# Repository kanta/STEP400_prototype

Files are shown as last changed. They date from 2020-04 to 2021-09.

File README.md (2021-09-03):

## STEP400_prototype

This repository has been retained for data storage, but is no longer being updated.

Please visit https://github.com/ponoor/STEP400.

---

STEP400_proto_r4

STEP400 is a 4-axis stepper motor driver designed for art or design projects. STEP400 combines the following elements into one single board:

- [Arduino Zero](https://www.arduino.cc/en/Guide/ArduinoZero)
- Ethernet shield
- Four stepper motor drivers
- Sensor inputs for homing and limiting

The current firmware is focused on working with [Open Sound Control](http://opensoundcontrol.org/) (OSC) via Ethernet, which is a common protocol for creative coding environments, like openFrameworks, Processing, Max, Unity, or Touch Designer.

Stepper driver chips are STMicroelectronics's [powerSTEP01](https://www.st.com/en/motor-drivers/powerstep01.html) which provide most of functionalities as a stepper driver.

## Repository Contents

This repo is temporal place for working. All information will be moved to a new repo when the clean up is done.

### Firmware
[/rev4/STEP400_proto_r4_firmware/STEP400_proto_r4_firmware/](https://github.com/kanta/STEP400_prototype/tree/master/rev4/STEP400_proto_r4_firmware/STEP400_proto_r4_firmware)

Source files for the firmware. Some Visual Studio files are included but you can open .ino file with Arduino IDE.

### Hardware
[/rev4/hardware/](https://github.com/kanta/STEP400_prototype/tree/master/rev4/hardware)

PCB design files for Eagle.

## Firmware dependency
- **[OSC Library](https://github.com/CNMAT/OSC)** from CNMAT
- **[Ponoor PowerSTEP01 Library](https://github.com/ponoor/Ponoor_PowerSTEP01_Library)**
- **[ArduinoJSON Library](https://arduinojson.org/)**
- **[Adafruit SleepyDog Arduino Library](https://github.com/adafruit/Adafruit_SleepyDog)**

## Examples
### Max
https://github.com/kanta/STEP400_prototype/blob/master/rev4/STEP400_proto_r4.maxpat

### openFrameworks
https://github.com/ponoor/step-series-example-openFrameworks

### Unity
https://github.com/ponoor/step-series-example-Unity

### Touch Designer
https://github.com/ponoor/step-series-example-TouchDesigner

## Documentation
Now working on [Wiki](https://github.com/kanta/STEP400_prototype/wiki).

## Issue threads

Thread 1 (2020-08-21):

Wikiの表記統一

kanta, 2020-08-21:
# ページ全体の見出しは#が1個
## 各コマンドのジャンルは#が2個
### コマンド自体は#が3個

コマンドは```これ（`が3個）```を`これ（`が1個）`に変更する

「返答」という文言は、block code から出す

返答の説明部分、メッセージの文字はblock code（`が1個）でくくる

yuskid, 2020-08-21:
正：block code（`が3個）でくくる

yuskid, 2020-08-21:
手順メモ
1. 「##」で検索、「###」に置換
2. 「```」で検索、適切な部分（単語/文節）を「`」に置換
3. 返答、メッセージ部分をチェックし、「```」でくくる
4. 改行チェック、エラーチェック

kanta, 2020-09-23:
初期値のリスト
https://docs.google.com/spreadsheets/d/1EAUpzARE69ip6_LolZAv3crpmXGsESjCOz6EqVY1lUo/edit#gid=0

kanta, 2020-09-23:
旧フォーマット
https://github.com/kanta/STEP400_prototype/wiki/%E8%A8%AD%E5%AE%9A%E3%83%BB%E3%83%A6%E3%83%BC%E3%83%86%E3%82%A3%E3%83%AA%E3%83%86%E3%82%A3_old

新フォーマット
https://github.com/kanta/STEP400_prototype/wiki/%E8%A8%AD%E5%AE%9A%E3%83%BB%E3%83%A6%E3%83%BC%E3%83%86%E3%82%A3%E3%83%AA%E3%83%86%E3%82%A3

kanta, 2020-09-23:
### `/setDestIp`
#### アーギュメント
なし

#### 実行可能タイミング
常時

#### 説明
モータの状態に変化があったときに通知するメッセージや、問い合わせへ返答するメッセージなどの送り先IPアドレス(`destIp`)を指定します。このメッセージを送信したIPアドレスを`destIp`に設定します。

また、`destIp`が設定されるまでは、STEP400からOSCメッセージの送信は行いませんので、一番最初にこのコマンドを送信してください。

#### 返答

```
/destIp (int)destIp[0] (int)destIp[1] (int)destIp[2] (int)destIp[3] (bool)isNewDestIp
```
| アーギュメント | 範囲 | 説明 |
| --- | --- | --- |
| destIp[0-3] | 0-255| destIpの各桁 |
| isNewDestIp | 0-1 | destIpが変更されたかどうかを示します。変更されていると1, すでに同じアドレスが設定されていた場合は0 |

#### 初期値
10.0.0.10

yuskid, 2020-09-23:
・見出し追加（アーギュメント、実行可能タイミング、説明、返答、初期値）
・リスト→表にする（箇条書き部分）

kanta, 2020-09-30:
(bool) enable
1で有効, 0で無効
範囲 0-1

Closed 2020-08-21.

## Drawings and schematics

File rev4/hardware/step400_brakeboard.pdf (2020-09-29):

GND | 10k 10k 10k 10k
Sheet: ABCD | 1 | 2 | 3 | 4 | 5 | 6 | ABCD 1 | 2 | 3 | 4 | 5 | 6

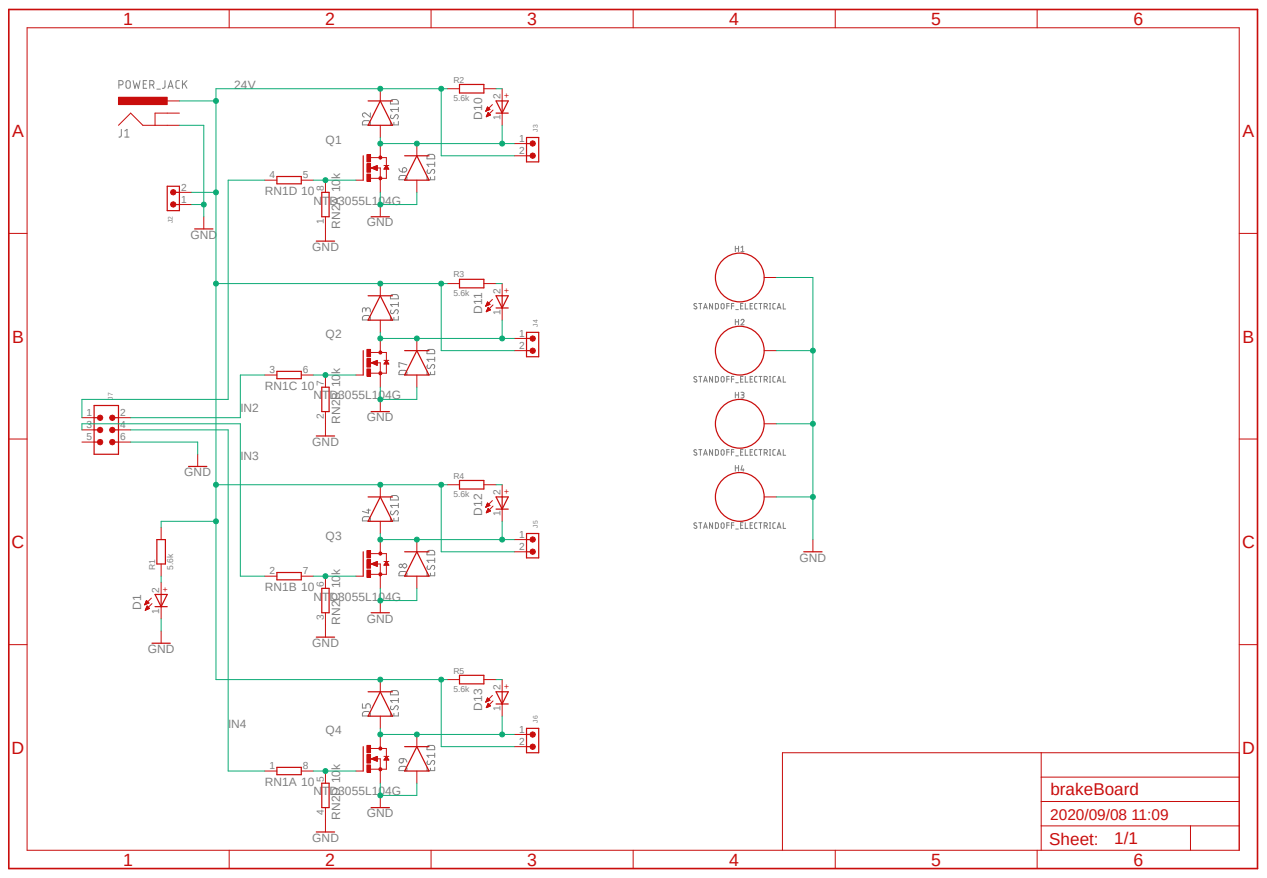
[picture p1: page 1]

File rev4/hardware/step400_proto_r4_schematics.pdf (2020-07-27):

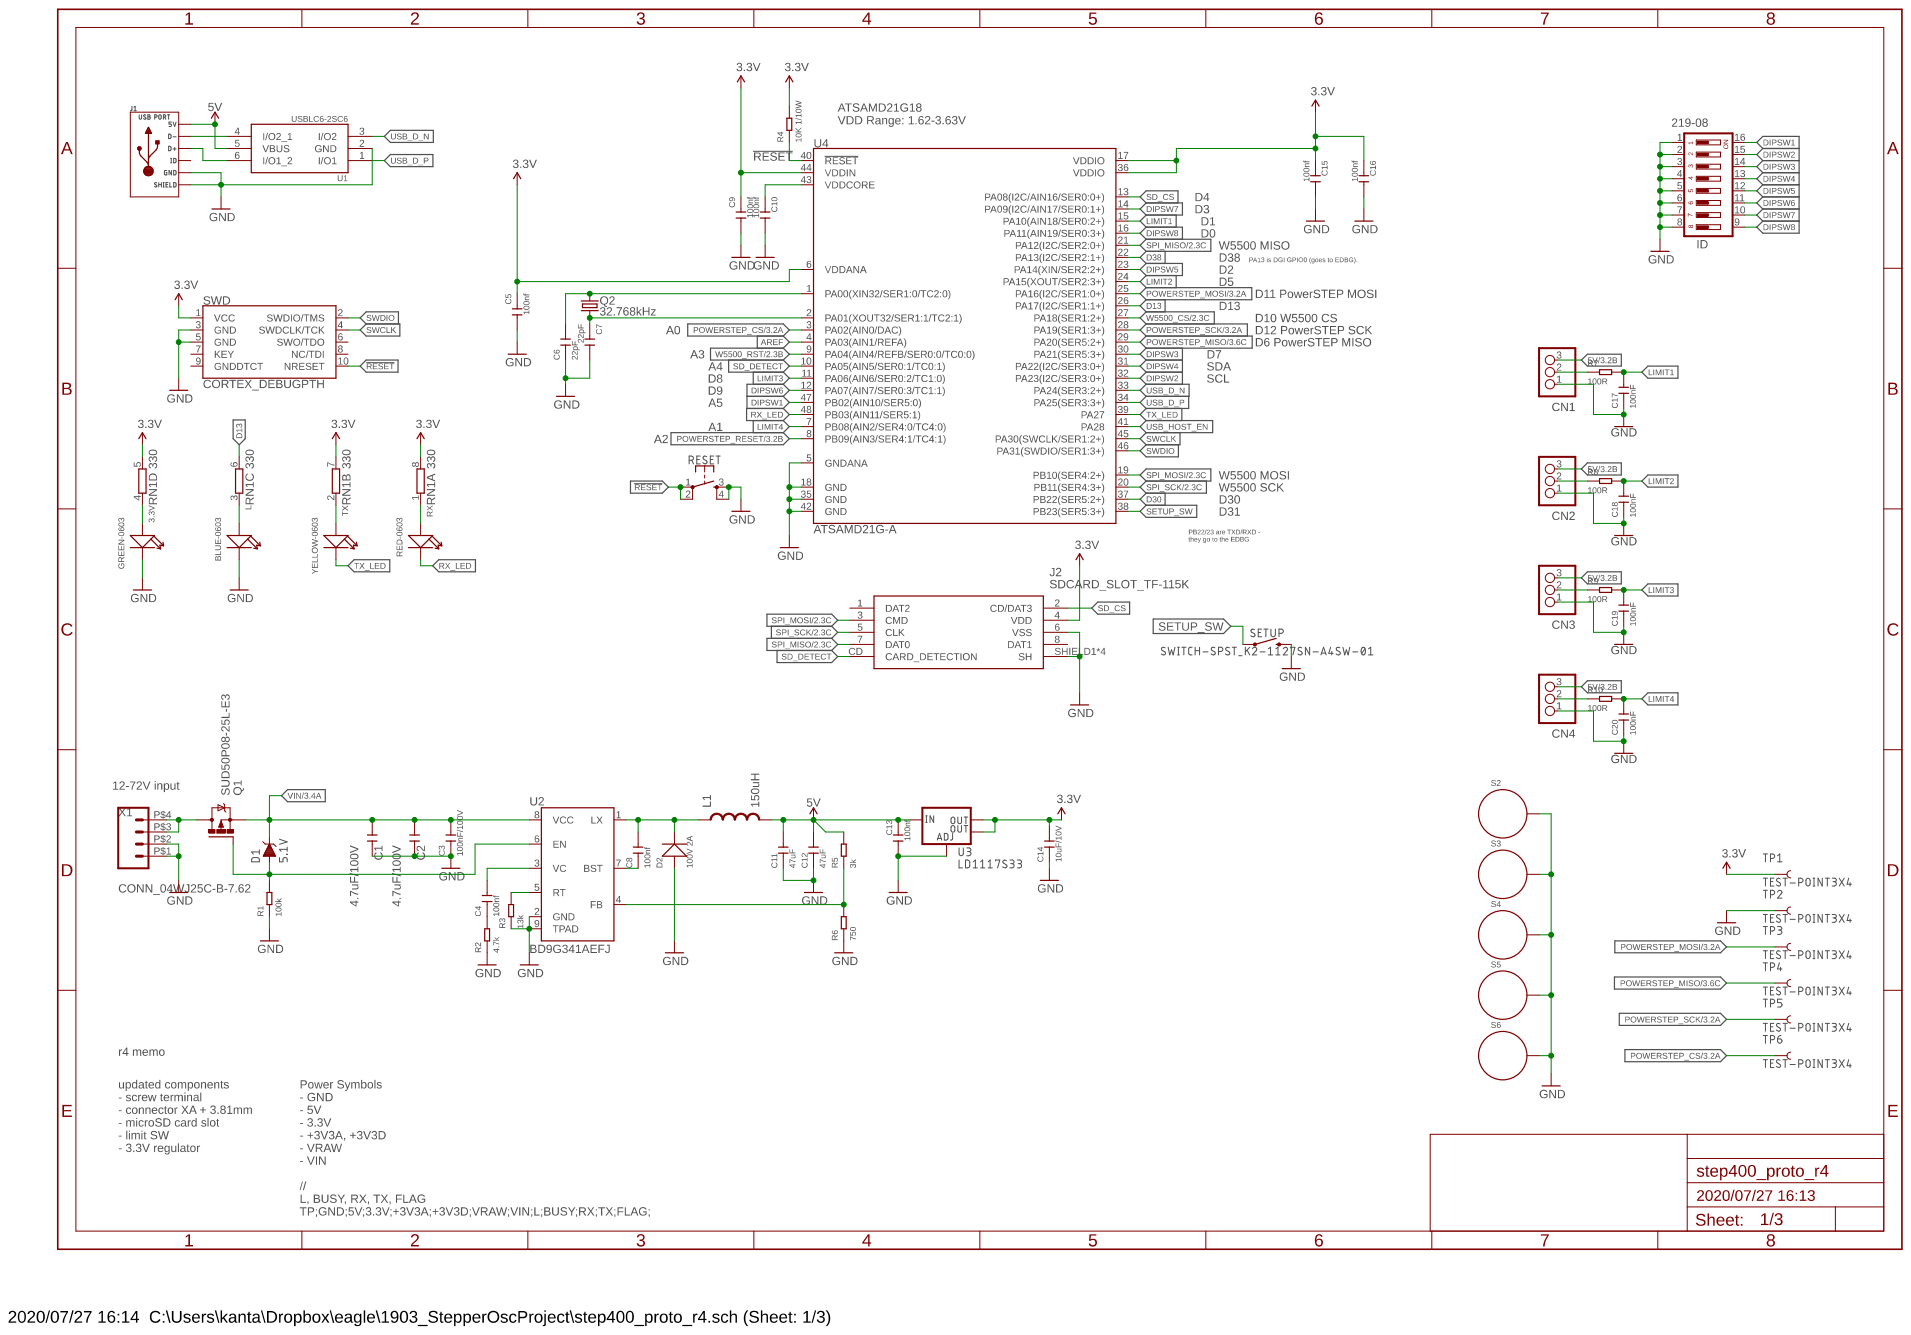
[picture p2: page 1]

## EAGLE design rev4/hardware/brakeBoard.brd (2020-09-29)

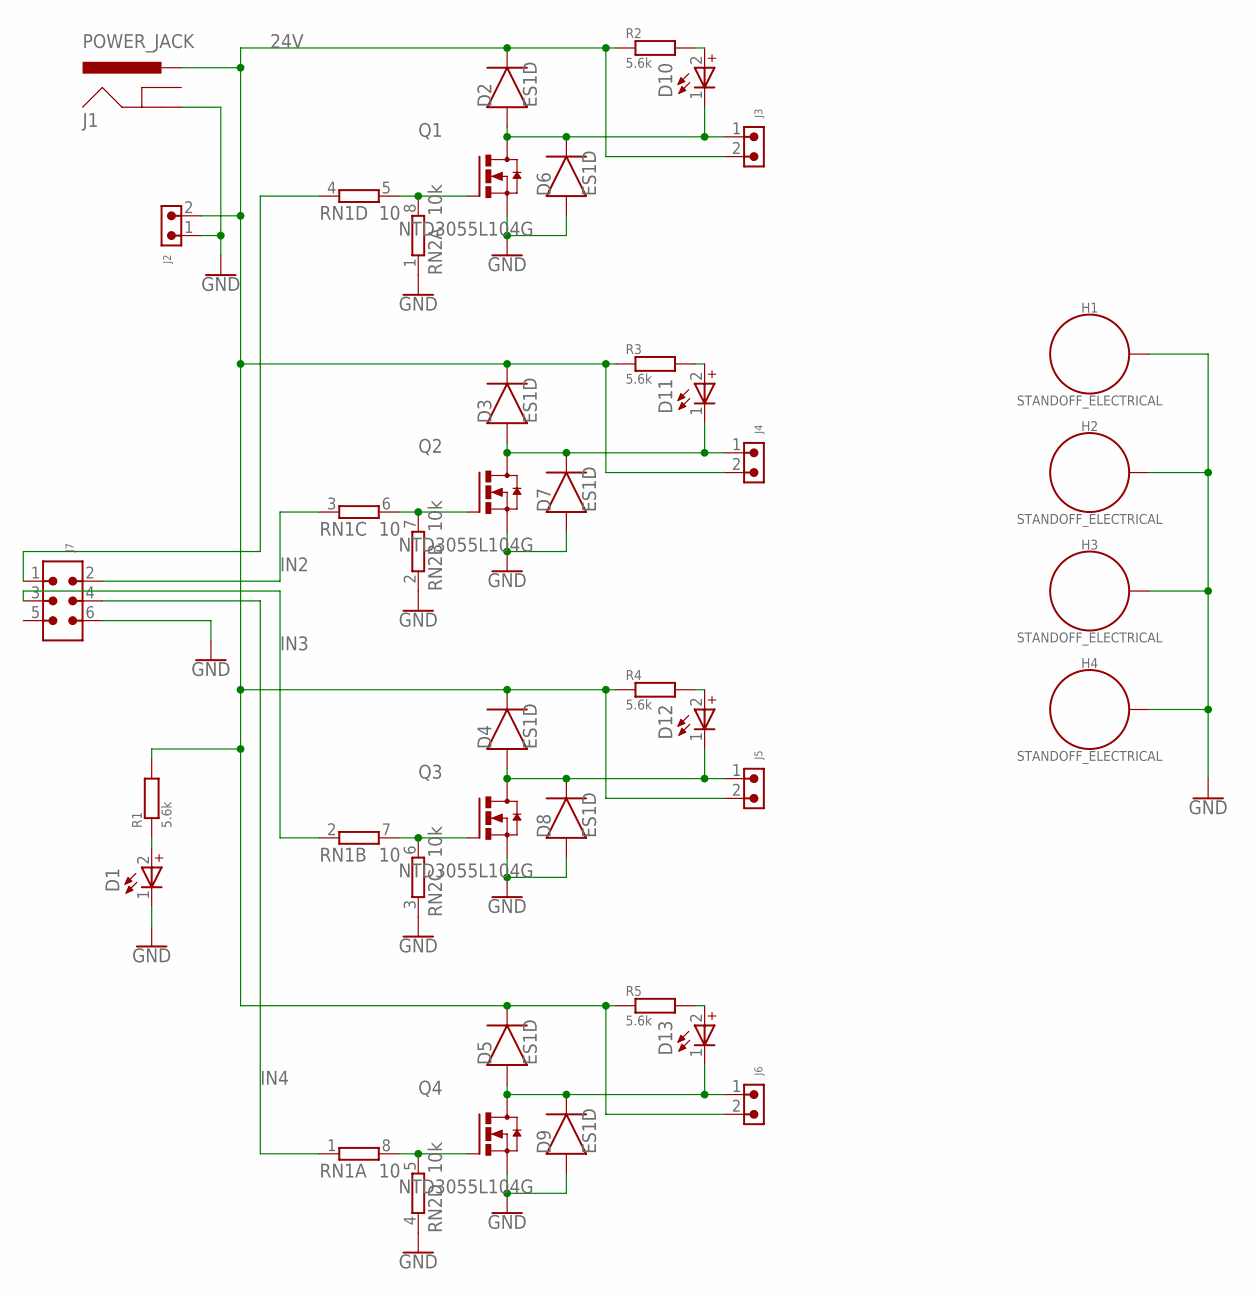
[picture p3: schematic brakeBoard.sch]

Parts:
D1, D10, D11, D12, D13: WL-SMCD_0603_150060GS55040; WL-SMCD_0603
D2, D3, D4, D5, D6, D7, D8, D9: ES1D; DIOM5226X290N
H1, H2, H3, H4: STANDOFF_ELECTRICAL; STANDOFF-ELECTRICAL
J1: POWER_JACK; POWER_JACK_PTH
J2: 691322310002
J3, J4, J5, J6: 691321300002
J7: 6120XX21621_61200621621; 61200621621
Q1, Q2, Q3, Q4: NTD3055L104G; DPAK3
R1, R2, R3, R4, R5: 5.6k; RESC2012X65
RN1: 10; CAY16_LONG_W
RN2: 10k; CAY16_LONG_W

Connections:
24V: D2.1 (C), D3.1 (C), D4.1 (C), D5.1 (C), J1.PWR, J2.2, J3.2, J4.2, J5.2, J6.2, R1.2, R2.1, R3.1, R4.1, R5.1
GND: D1.1 (_), D6.2 (A), D7.2 (A), D8.2 (A), D9.2 (A), H1.P1, H2.P1, H3.P1, H4.P1, J1.GND, J2.1, J7.6, Q1.2 (S), Q2.2 (S), Q3.2 (S), Q4.2 (S), RN2.1, RN2.2 (1), RN2.3 (1), RN2.4 (1)
IN1: J7.1, RN1.4 (1)
IN2: J7.2, RN1.3 (1)
IN3: J7.3, RN1.2 (1)
IN4: J7.4, RN1.1
unnamed: D2.2 (A), D6.1 (C), D10.1 (_), J3.1, Q1.3 (D)
unnamed: D10.2 (+), R2.2
unnamed: Q1.1 (G), RN1.5 (2), RN2.8 (2)
unnamed: D3.2 (A), D7.1 (C), D11.1 (_), J4.1, Q2.3 (D)
unnamed: D11.2 (+), R3.2
unnamed: D4.2 (A), D8.1 (C), D12.1 (_), J5.1, Q3.3 (D)
unnamed: D12.2 (+), R4.2
unnamed: D5.2 (A), D9.1 (C), D13.1 (_), J6.1, Q4.3 (D)
unnamed: D13.2 (+), R5.2
unnamed: Q4.1 (G), RN1.8 (2), RN2.5 (2)
unnamed: Q3.1 (G), RN1.7 (2), RN2.6 (2)
unnamed: Q2.1 (G), RN1.6 (2), RN2.7 (2)
unnamed: D1.2 (+), R1.1

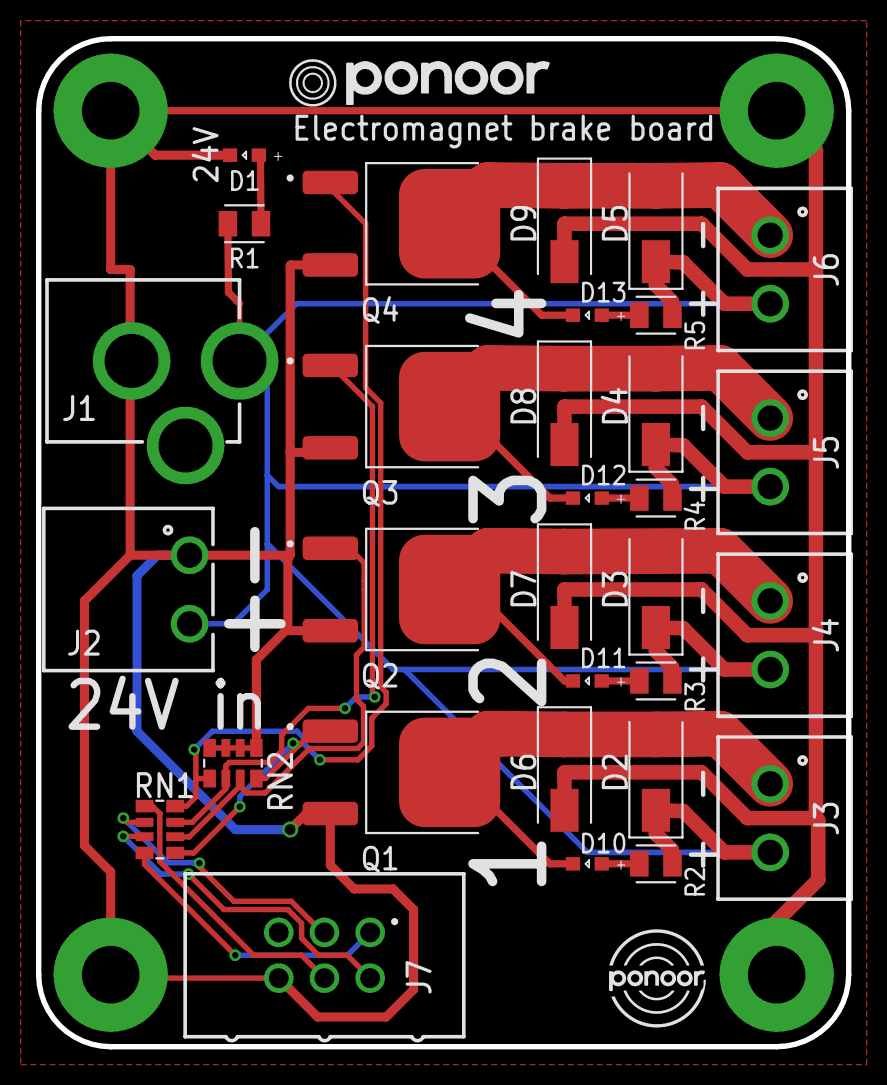
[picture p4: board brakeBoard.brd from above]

Board: 2 copper layers, 45.0 x 56.0 mm, 38 parts (1 on the bottom side), 19 nets.

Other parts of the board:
U$1: PONOOR_LOGO_6MM
U$2, U$3: PONOOR_TEXT_15MM

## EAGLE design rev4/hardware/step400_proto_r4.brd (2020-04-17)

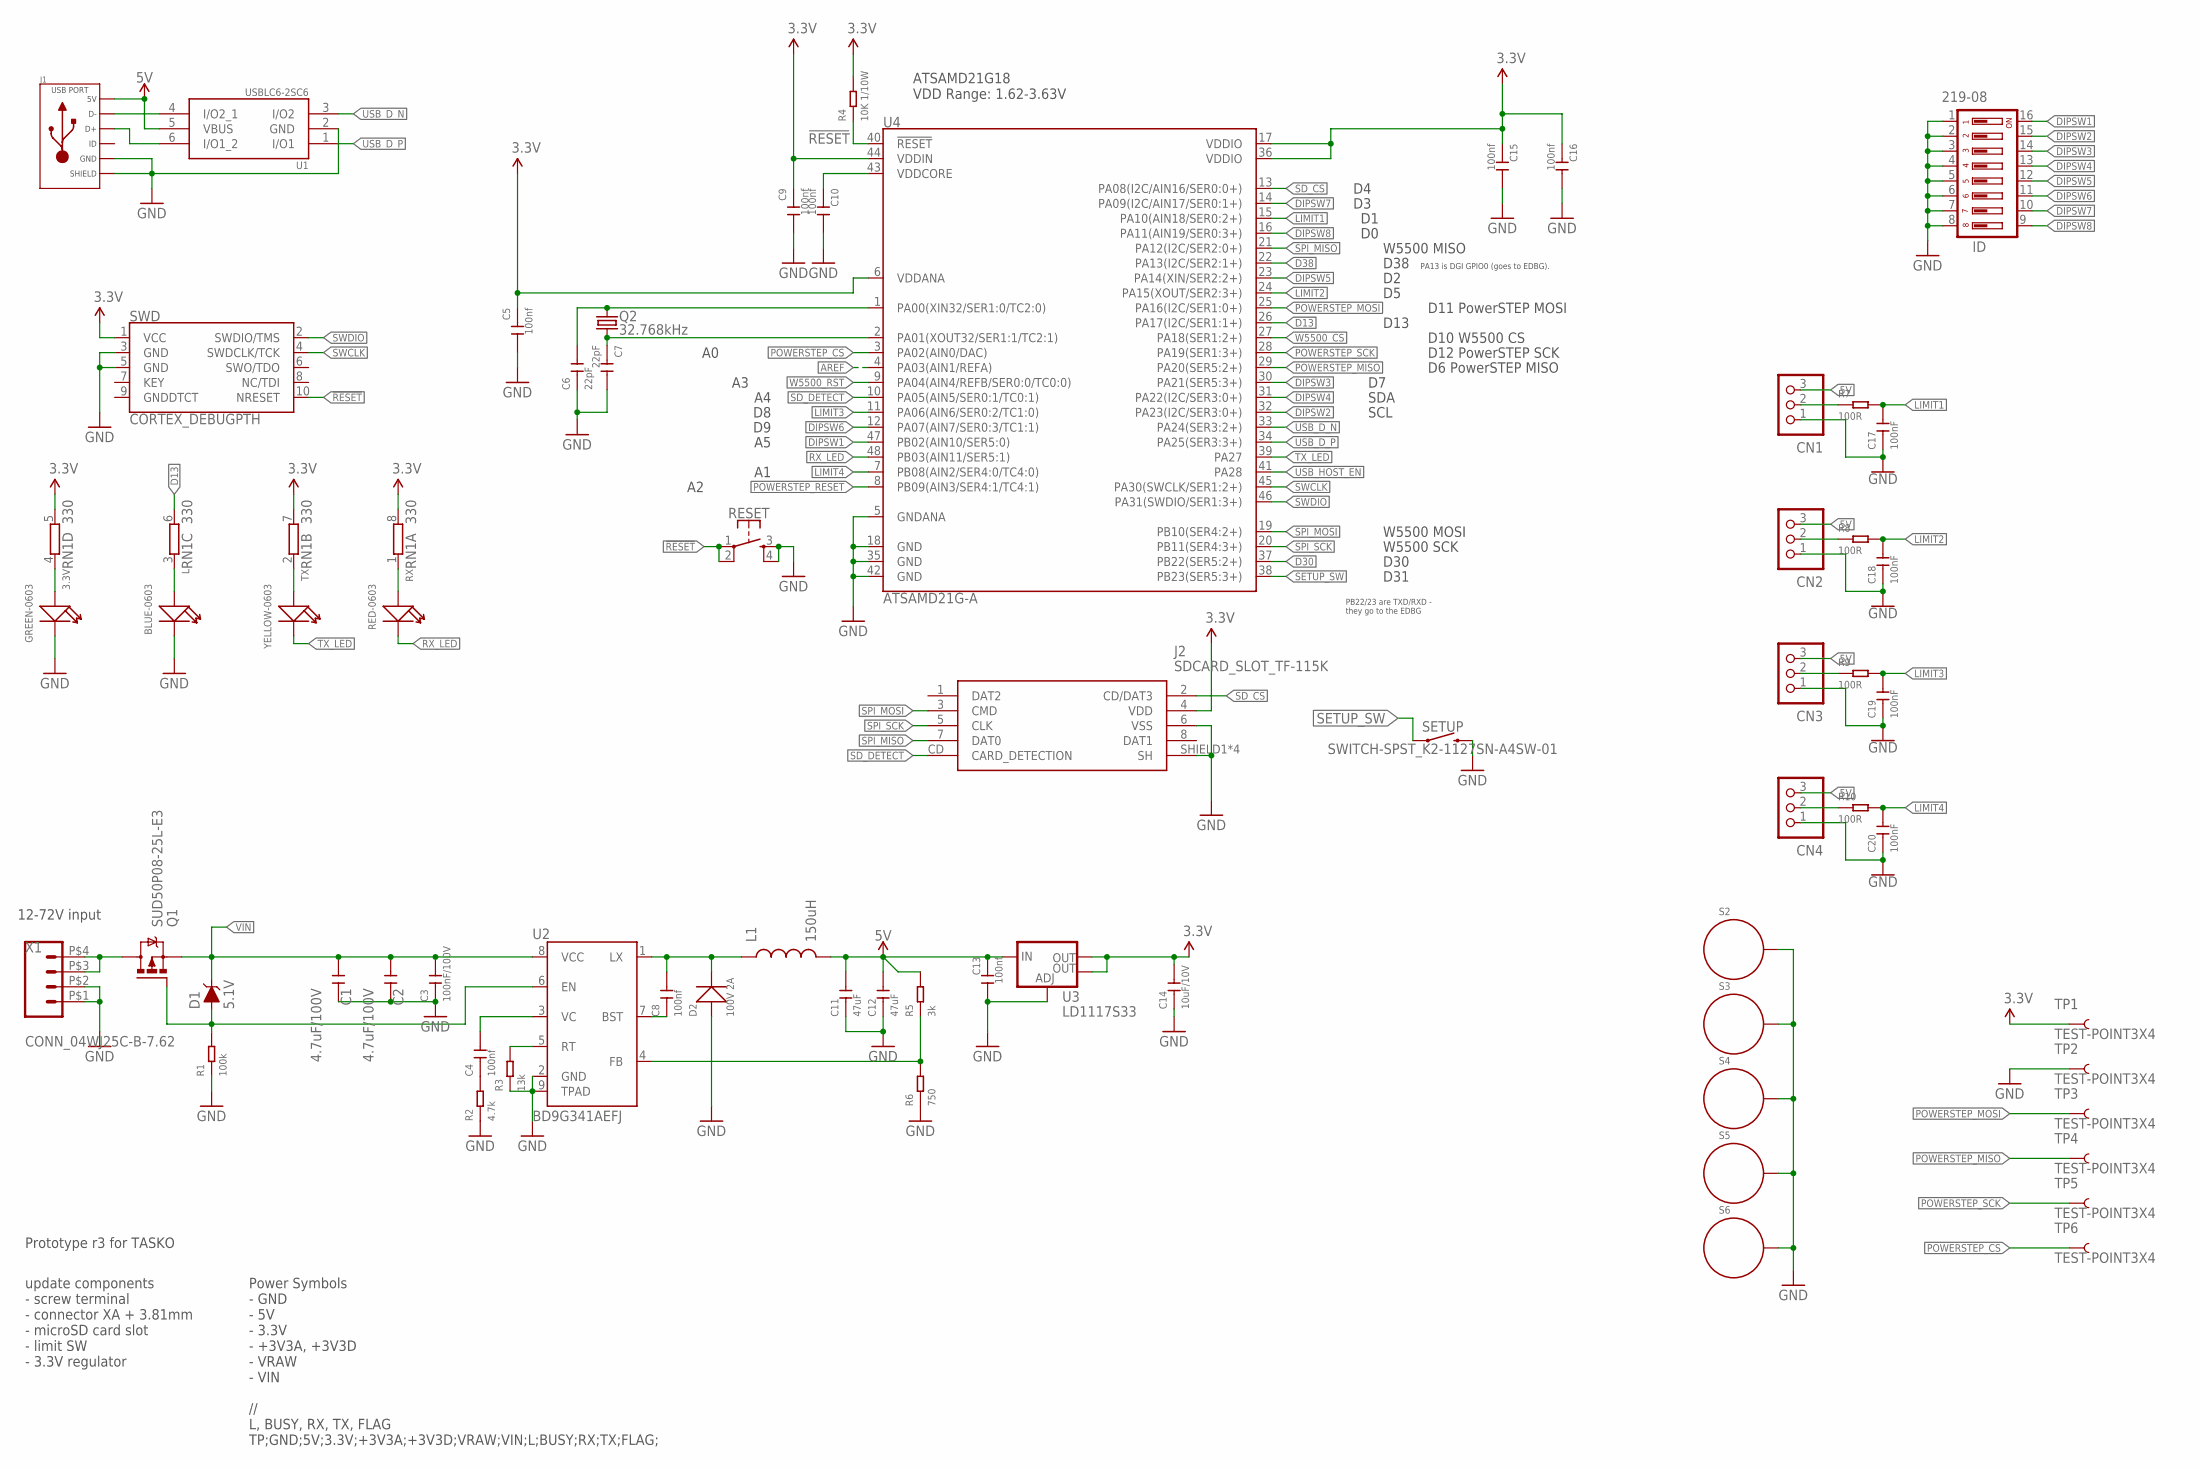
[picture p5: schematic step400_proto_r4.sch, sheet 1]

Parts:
3.3V: GREEN-0603; LED-0603
C1, C2: 4.7uF/100V; C1210
C3: 100nF/100V; C0805
C4, C8: 100nf; C0603
C5, C9, C10, C13, C15, C16: 100nf; C0402
C6, C7: 22pF; C0402
C11, C12: 47uF; C1206
C14: 10uF/10V; C0805
C17, C18, C19, C20: 100nF; C0402
CN1, CN2, CN3, CN4: B3B-XASK-1
D1: 5.1V; SOD-323
D2: 100V 2A; DO-214AC
ID: 219-08; CTS-219-08
J1: USB_MICRO_10118193-0001LF; MICROUSB-FCI-PBAN
J2: SDCARD_SLOT_TF-115K; TF-115K
L: BLUE-0603; LED-0603
L1: 150uH; L5045_L
Q1: SUD50P08-25L-E3; D-PAK_TO252AA
Q2: 32.768kHz; FC-135
R1: 100k; R0603
R2: 4.7k; R0603
R3: 13k; R0603
R4: 10K 1/10W; R0603
R5: 3k; R0603
R6: 750; R0603
R7, R8, R9, R10: 100R; R0603
RESET: MOMENTARY-SWITCH-SPST-2-SMD-5.2MM; TACTILE_SWITCH_SMD_5.2MM
RN1: 330; CAY16_LONG_W
RX: RED-0603; LED-0603
S2, S3, S4, S5, S6: STANDOFF_ELECTRICAL; STANDOFF-ELECTRICAL
SETUP: SWITCH-SPST_K2-1127SN-A4SW-01; K2-1127SN-A4SW-01
SWD: CORTEX_DEBUGPTH; 2X5-PTH-1.27MM
TP1, TP2, TP3, TP4, TP5, TP6: TEST-POINT3X4; PAD.03X.04
TX: YELLOW-0603; LED-0603
U1: USBLC6-2SC6; SOT23-6L
U2: BD9G341AEFJ; SOIC127P600X100-9N
U3: LD1117S33; SOT223
U4: ATSAMD21G-A; TQFP-48
X1: CONN_04WJ25C-B-7.62; WJ25C-B-7.62-4P

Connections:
3.3V: C5.1, C9.1, C14.2, C15.1, C16.1, J2.4 (VDD), R4.2, RN1.5 (2), RN1.7 (2), RN1.8 (2), SWD.1 (VCC), TP1.P$1, U3.2 (OUT), U3.4 (OUT), U4.6 (VDDANA), U4.17 (VDDIO), U4.36 (VDDIO), U4.44 (VDDIN); also elsewhere on the board
5V: C11.2, C12.2, C13.1, CN1.3, CN2.3, CN3.3, CN4.3, J1.1 (5V), L1.P$2 (2), R5.2, U1.5 (VBUS), U3.3 (IN); also elsewhere on the board
!RESET: R4.1, RESET.1, RESET.2, SWD.10 (NRESET), U4.40 (!RESET!)
AREF: U4.4 (PA03(AIN1/REFA))
D13: RN1.6 (2), U4.26 (PA17(I2C/SER1:1+))
D30: U4.37 (PB22(SER5:2+))
D38: U4.22 (PA13(I2C/SER2:1+))
D+: J1.3 (D+), U1.6 (I/O1_2)
DIPSW1: ID.16, U4.47 (PB02(AIN10/SER5:0))
DIPSW2: ID.15, U4.32 (PA23(I2C/SER3:0+))
DIPSW3: ID.14, U4.30 (PA21(SER5:3+))
DIPSW4: ID.13, U4.31 (PA22(I2C/SER3:0+))
DIPSW5: ID.12, U4.23 (PA14(XIN/SER2:2+))
DIPSW6: ID.11, U4.12 (PA07(AIN7/SER0:3/TC1:1))
DIPSW7: ID.10, U4.14 (PA09(I2C/AIN17/SER0:1+))
DIPSW8: ID.9, U4.16 (PA11(AIN19/SER0:3+))
GND: 3.3V.-, C1.2, C2.2, C3.1, C5.2, C6.1, C7.2, C9.2, C10.2, C11.1, C12.1, C13.2, C14.1, C15.2, C16.2, C17.1, C18.1, C19.1, C20.1, CN1.1, CN2.1, CN3.1, CN4.1, D2.1 (+), ID.1, ID.2, ID.3, ID.4, ID.5, ID.6, ID.7, ID.8, J1.5 (GND), J1.S1 (SLD), J1.S2 (SLD), J1.S3 (SLD), J1.S4 (SLD), J1.S5 (SLD), J1.S6 (SLD), J1.S7 (SLD), J1.S8 (SLD), J2.6 (VSS), J2.SHIELD1 (SH), J2.SHIELD2 (SH), J2.SHIELD3 (SH), J2.SHIELD4 (SH), L.-, R1.1, R2.1, R3.1, R6.1, RESET.3, RESET.4, S2.P1, S3.P1, S4.P1, S5.P1, S6.P1, SETUP.P$3 (2), SETUP.P$4 (2), SWD.3 (GND), SWD.5 (GND), TP2.P$1, U1.2 (GND), U2.2 (GND), U2.9 (TPAD), U3.1 (ADJ), U4.5 (GNDANA), U4.18 (GND), U4.35 (GND), U4.42 (GND), X1.P$1 (1), X1.P$2 (2); also elsewhere on the board
LIMIT1: C17.2, R7.2, U4.15 (PA10(AIN18/SER0:2+))
LIMIT2: C18.2, R8.2, U4.24 (PA15(XOUT/SER2:3+))
LIMIT3: C19.2, R9.2, U4.11 (PA06(AIN6/SER0:2/TC1:0))
LIMIT4: C20.2, R10.2, U4.7 (PB08(AIN2/SER4:0/TC4:0))
unnamed: C6.2, Q2.P$2 (2), U4.1 (PA00(XIN32/SER1:0/TC2:0))
unnamed: C4.1, R2.2
unnamed: C7.1, Q2.P$1 (1), U4.2 (PA01(XOUT32/SER1:1/TC2:1))
unnamed: RN1.1, RX.+
unnamed: RN1.2 (1), TX.+
unnamed: R5.1, R6.2, U2.4 (FB)
unnamed: D1.A, Q1.1 (G), R1.2, U2.6 (EN)
unnamed: R3.2, U2.5 (RT)
unnamed: L.+, RN1.3 (1)
unnamed: 3.3V.+, RN1.4 (1)
unnamed: C4.2, U2.3 (VC)
unnamed: CN1.2, R7.1
unnamed: C8.1, U2.7 (BST)
unnamed: CN2.2, R8.1
unnamed: C8.2, D2.2 (-), L1.P$1 (1), U2.1 (LX)
unnamed: CN3.2, R9.1
unnamed: CN4.2, R10.1
unnamed: J1.2 (D-), U1.4 (I/O2_1)
POWERSTEP_CS: TP6.P$1, U4.3 (PA02(AIN0/DAC)); also elsewhere on the board
POWERSTEP_MISO: TP4.P$1, U4.29 (PA20(SER5:2+)); also elsewhere on the board
POWERSTEP_MOSI: TP3.P$1, U4.25 (PA16(I2C/SER1:0+)); also elsewhere on the board
POWERSTEP_RESET: U4.8 (PB09(AIN3/SER4:1/TC4:1)); also elsewhere on the board
POWERSTEP_SCK: TP5.P$1, U4.28 (PA19(SER1:3+)); also elsewhere on the board
RX_LED: RX.-, U4.48 (PB03(AIN11/SER5:1))
SD_CS: J2.2 (CD/DAT3), U4.13 (PA08(I2C/AIN16/SER0:0+))
SD_DETECT: J2.CD (CARD_DETECTION), U4.10 (PA05(AIN5/SER0:1/TC0:1))
SETUP_SW: SETUP.P$1 (1), SETUP.P$2 (1), U4.38 (PB23(SER5:3+))
SPI_MISO: J2.7 (DAT0), U4.21 (PA12(I2C/SER2:0+)); also elsewhere on the board
SPI_MOSI: J2.3 (CMD), U4.19 (PB10(SER4:2+)); also elsewhere on the board
SPI_SCK: J2.5 (CLK), U4.20 (PB11(SER4:3+)); also elsewhere on the board
SWCLK: SWD.4 (SWDCLK/TCK), U4.45 (PA30(SWCLK/SER1:2+))
SWDIO: SWD.2 (SWDIO/TMS), U4.46 (PA31(SWDIO/SER1:3+))
TX_LED: TX.-, U4.39 (PA27)
USB_D_N: U1.3 (I/O2), U4.33 (PA24(SER3:2+))
USB_D_P: U1.1 (I/O1), U4.34 (PA25(SER3:3+))
USB_HOST_EN: U4.41 (PA28)
VDDCORE: C10.1, U4.43 (VDDCORE)
VIN: C1.1, C2.1, C3.2, D1.C, Q1.3 (S), U2.8 (VCC); also elsewhere on the board
VRAW: Q1.4 (D), X1.P$3 (3), X1.P$4 (4)
W5500_CS: U4.27 (PA18(SER1:2+)); also elsewhere on the board
W5500_RST: U4.9 (PA04(AIN4/REFB/SER0:0/TC0:0)); also elsewhere on the board

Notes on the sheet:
PB22/23 are TXD/RXD - they go to the EDBG
PA13 is DGI GPIO0 (goes to EDBG).
ATSAMD21G18 VDD Range: 1.62-3.63V
D30
D12 PowerSTEP SCK
D10 W5500 CS
D11 PowerSTEP MOSI
D13
D6 PowerSTEP MISO
D38
12-72V input
W5500 MISO
W5500 MOSI
W5500 SCK
SDA
SCL
D31
Prototype r3 for TASKO
update components - screw terminal - connector XA + 3.81mm - microSD card slot - limit SW - 3.3V regulator
Power Symbols - GND - 5V - 3.3V - +3V3A, +3V3D - VRAW - VIN // L, BUSY, RX, TX, FLAG TP;GND;5V;3.3V;+3V3A;+3V3D;VRAW;VIN;L;BUSY;RX;TX;FLAG;

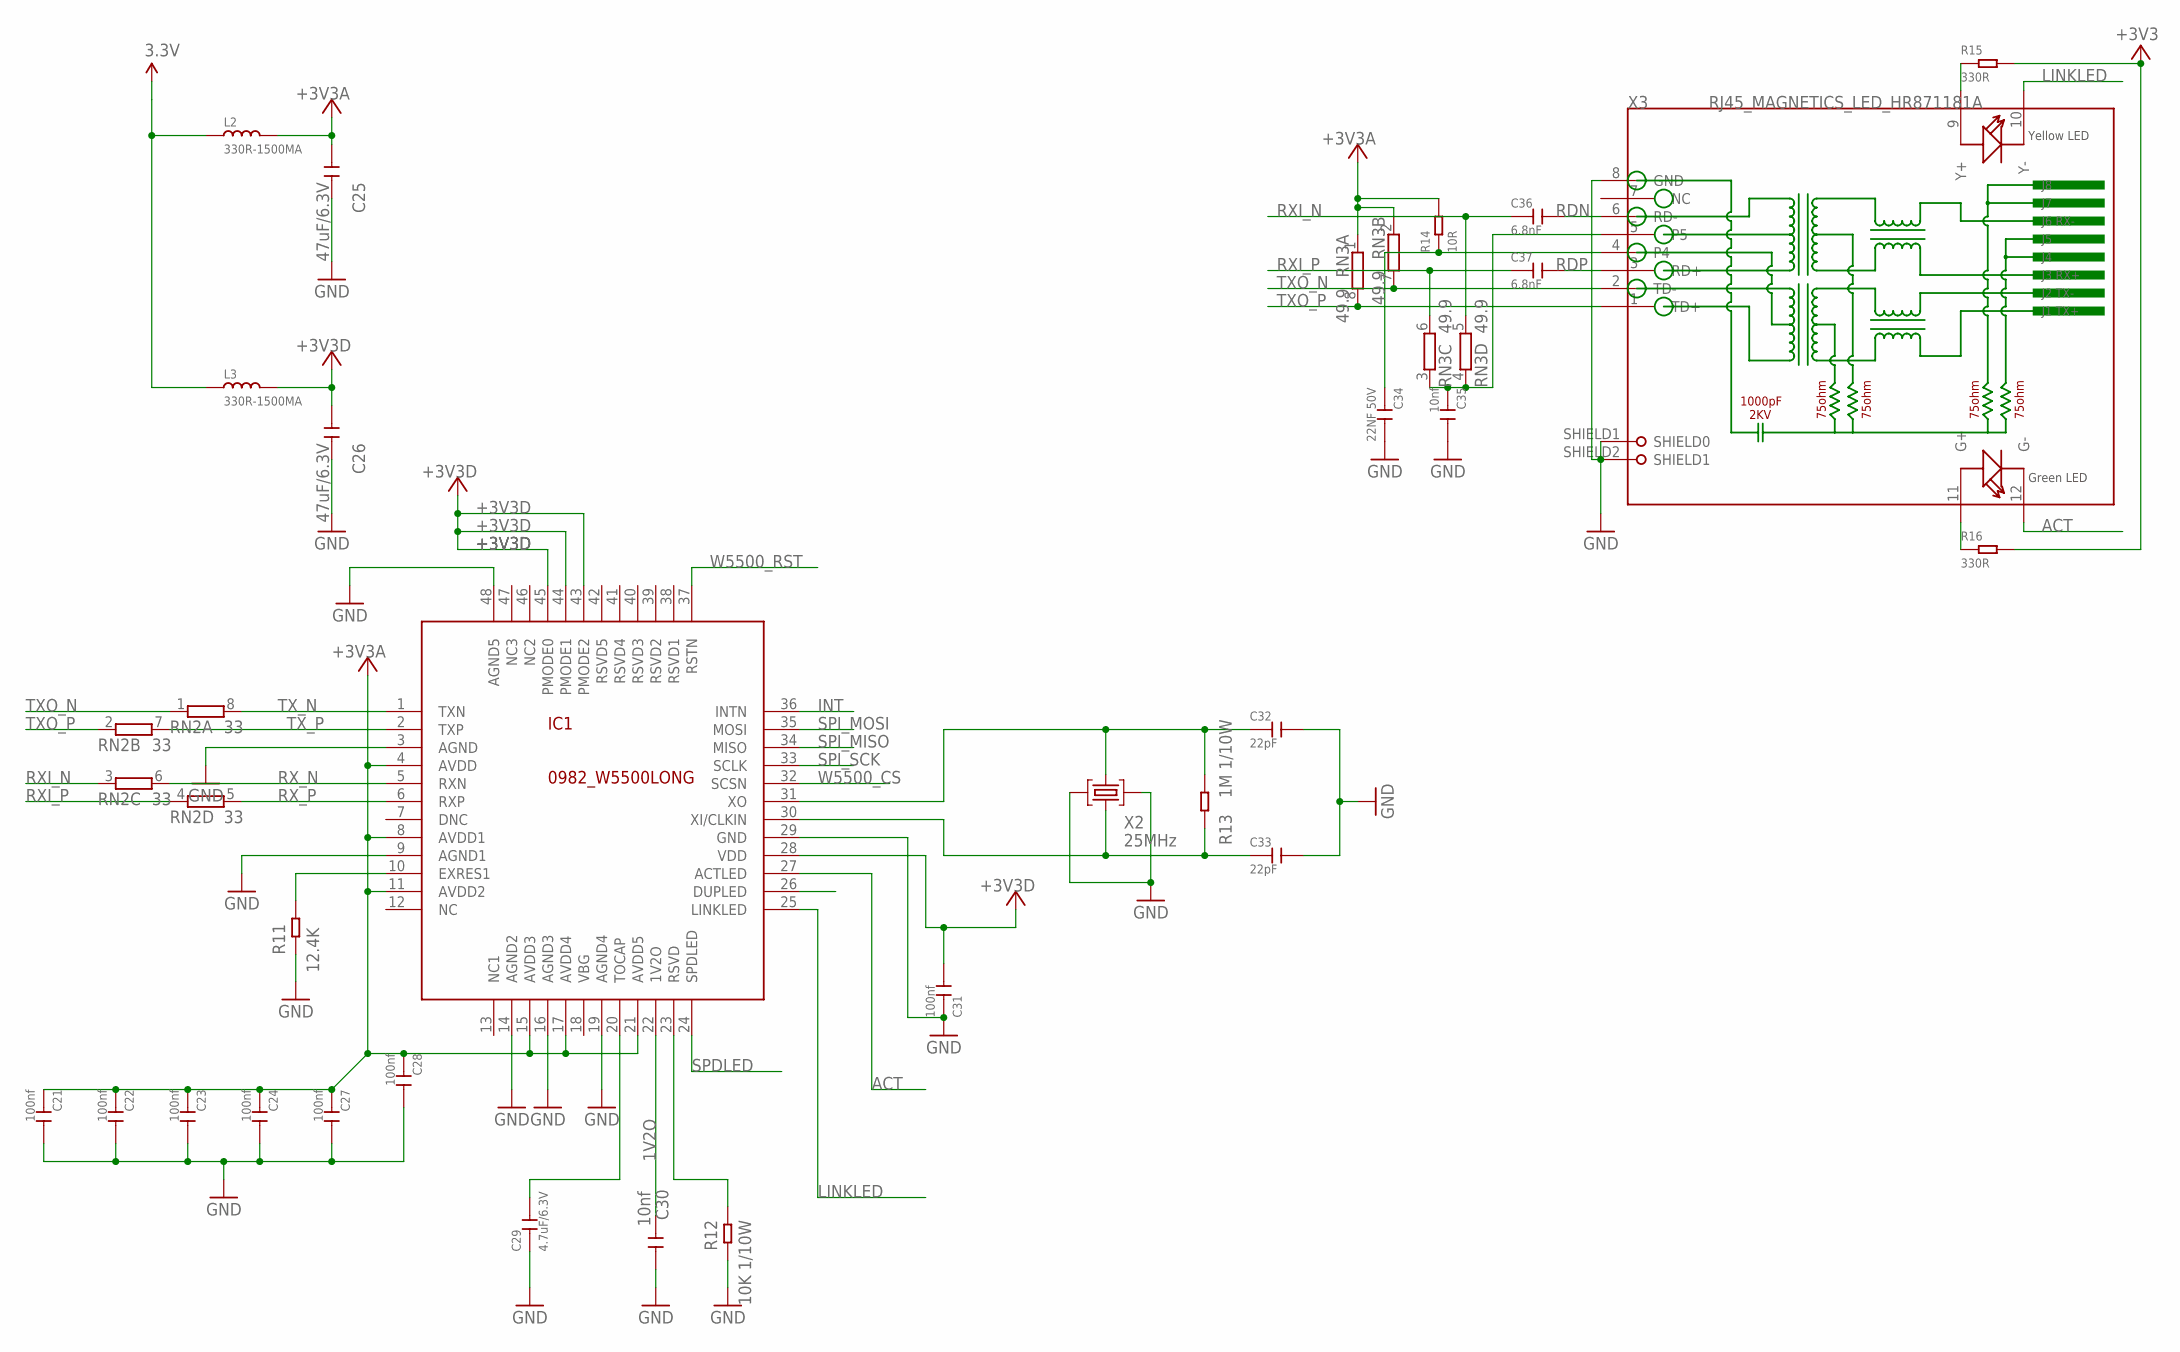
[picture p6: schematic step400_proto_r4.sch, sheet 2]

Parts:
C21, C22, C23, C24, C27, C28, C31: 100nf; C0402
C25, C26: 47uF/6.3V; C1206
C29: 4.7uF/6.3V; C0603
C30, C35: 10nf; C0402
C32, C33: 22pF; C0402
C34: 22NF 50V; C0402
C36, C37: 6.8nF; C0402
IC1: 0982_W5500LONG; TQFP48-LONG
L2, L3: 330R-1500MA; L0805
R11: 12.4K; R0603
R12: 10K 1/10W; R0603
R13: 1M 1/10W; R0603
R14: 10R; R0603
R15, R16: 330R; R0603
RN2: 33; CAY16_LONG_W
RN3: 49.9; CAY16_LONG_W
X2: 25MHz; CRYSTAL-3.2-2.5
X3: RJ45_MAGNETICS_LED_HR871181A; HR871181A

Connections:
1V2O: C30.2, IC1.22 (1V2O)
3.3V: L2.1, L3.1, R15.2, R16.2; also elsewhere on the board
+3V3A: C21.1, C22.1, C23.1, C24.1, C25.1, C27.1, C28.1, IC1.4 (AVDD), IC1.8 (AVDD1), IC1.11 (AVDD2), IC1.15 (AVDD3), IC1.17 (AVDD4), IC1.21 (AVDD5), L2.2, R14.2, RN3.1, RN3.2 (1)
+3V3D: C26.1, C31.2, IC1.28 (VDD), IC1.43 (PMODE2), IC1.44 (PMODE1), IC1.45 (PMODE0), L3.2
ACT: IC1.27 (ACTLED), X3.12 (G-)
FDXLED: IC1.26 (DUPLED)
GND: C21.2, C22.2, C23.2, C24.2, C25.2, C26.2, C27.2, C28.2, C29.1, C30.1, C31.1, C32.2, C33.2, C34.2, C35.2, IC1.3 (AGND), IC1.9 (AGND1), IC1.14 (AGND2), IC1.16 (AGND3), IC1.19 (AGND4), IC1.29 (GND), IC1.48 (AGND5), R11.1, R12.1, X2.2 (GND), X2.4 (GND), X3.8 (GND), X3.SHIELD1 (SHIELD0), X3.SHIELD2 (SHIELD1); also elsewhere on the board
INT: IC1.36 (INTN)
LINKLED: IC1.25 (LINKLED), X3.10 (Y-)
unnamed: C32.1, IC1.31 (XO), R13.1, X2.3 (C2)
unnamed: C34.1, R14.1, X3.4
unnamed: C35.1, RN3.3 (1), RN3.4 (1), X3.5
unnamed: R15.1, X3.9 (Y+)
unnamed: R16.1, X3.11 (G+)
unnamed: IC1.23 (RSVD), R12.2
unnamed: C29.2, IC1.20 (TOCAP)
unnamed: IC1.10 (EXRES1), R11.2
NC: IC1.12 (NC)
OSC2E2: C33.1, IC1.30 (XI/CLKIN), R13.2, X2.1 (C1)
RDN: C36.2, X3.6 (RD-)
RDP: C37.2, X3.3 (RD+)
RSVD1: IC1.38 (RSVD1)
RSVD2: IC1.39 (RSVD2)
RSVD3: IC1.40 (RSVD3)
RXI_N: C36.1, RN2.3 (1), RN3.5 (2)
RXI_P: C37.1, RN2.4 (1), RN3.6 (2)
RX_N: IC1.5 (RXN), RN2.6 (2)
RX_P: IC1.6 (RXP), RN2.5 (2)
SPDLED: IC1.24 (SPDLED)
SPI_MISO: IC1.34 (MISO); also elsewhere on the board
SPI_MOSI: IC1.35 (MOSI); also elsewhere on the board
SPI_SCK: IC1.33 (SCLK); also elsewhere on the board
TXO_N: RN2.1, RN3.7 (2), X3.2 (TD-)
TXO_P: RN2.2 (1), RN3.8 (2), X3.1 (TD+)
TX_N: IC1.1 (TXN), RN2.8 (2)
TX_P: IC1.2 (TXP), RN2.7 (2)
W5500_CS: IC1.32 (SCSN); also elsewhere on the board
W5500_RST: IC1.37 (RSTN); also elsewhere on the board

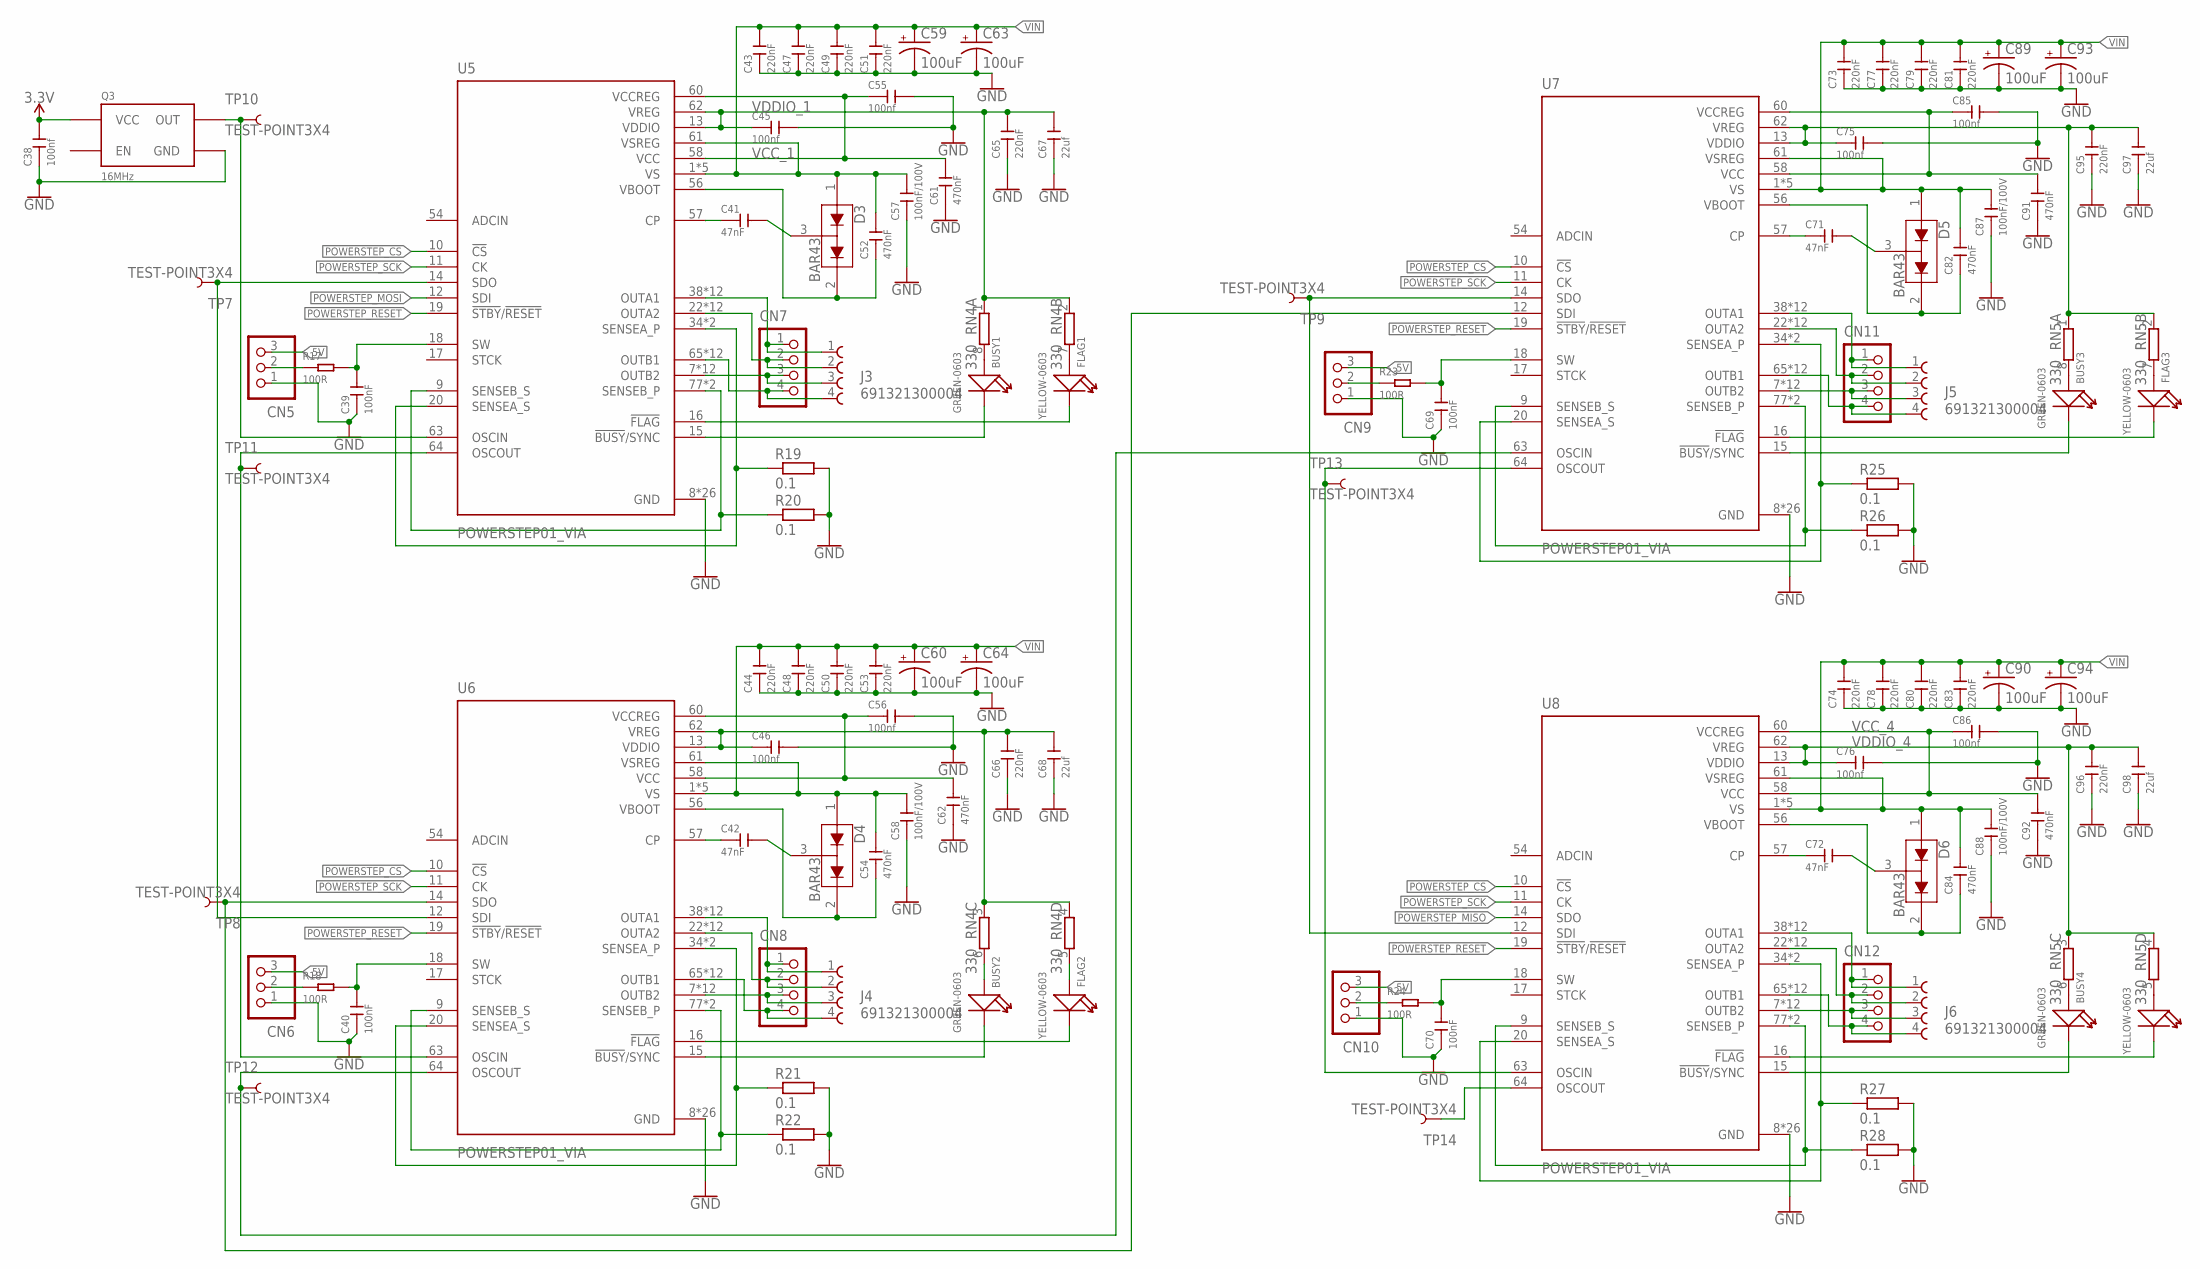
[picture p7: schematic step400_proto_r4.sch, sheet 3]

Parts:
BUSY1, BUSY2, BUSY3, BUSY4: GREEN-0603; LED-0603
C38, C45, C46, C55, C56, C75, C76, C85, C86: 100nf; C0402
C39, C40, C69, C70: 100nF; C0402
C41, C42, C71, C72: 47nF; C0805
C43, C44, C47, C48, C49, C50, C51, C53, C73, C74, C77, C78, C79, C80, C81, C83: 220nF; C0805
C52, C54, C61, C62, C82, C84, C91, C92: 470nF; C0603
C57, C58, C87, C88: 100nF/100V; C0805
C59, C60, C63, C64, C89, C90, C93, C94: 100uF; E5-10,5
C65, C66, C95, C96: 220nF; C0402
C67, C68, C97, C98: 22uf; C0805
CN5, CN6, CN9, CN10: B3B-XASK-1
CN7, CN8, CN11, CN12: B4B-XASK-1
D3, D4, D5, D6: BAR43; SOT23-3
FLAG1, FLAG2, FLAG3, FLAG4: YELLOW-0603; LED-0603
J3, J4, J5, J6: 691321300004
Q3: 16MHz; SG5032
R17, R18, R23, R24: 100R; R0603
R19, R20, R21, R22, R25, R26, R27, R28: 0.1; RESC6332X71N
RN4, RN5: 330; CAY16_LONG_W
TP7, TP8, TP9, TP10, TP11, TP12, TP13, TP14: TEST-POINT3X4; PAD.03X.04
U5, U6, U7, U8: POWERSTEP01_VIA; IC_POWERSTEP01_VIA

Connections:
3.3V: C38.2, Q3.4 (VCC); also elsewhere on the board
5V: CN5.3, CN6.3, CN9.3, CN10.3; also elsewhere on the board
GND: C38.1, C39.1, C40.1, C43.1, C44.1, C45.2, C46.2, C47.1, C48.1, C49.1, C50.1, C51.1, C53.1, C55.2, C56.2, C57.1, C58.1, C59.-, C60.-, C61.1, C62.1, C63.-, C64.-, C65.1, C66.1, C67.1, C68.1, C69.1, C70.1, C73.1, C74.1, C75.2, C76.2, C77.1, C78.1, C79.1, C80.1, C81.1, C83.1, C85.2, C86.2, C87.1, C88.1, C89.-, C90.-, C91.1, C92.1, C93.-, C94.-, C95.1, C96.1, C97.1, C98.1, CN5.1, CN6.1, CN9.1, CN10.1, Q3.2 (GND), R19.2, R20.2, R21.2, R22.2, R25.2, R26.2, R27.2, R28.2, U5.8 (GND), U5.21 (GND), U5.59 (GND), U5.EPAD9 (GND), U5.EPAD9_VIA1 (GND), U5.EPAD9_VIA2 (GND), U5.EPAD9_VIA3 (GND), U5.EPAD9_VIA4 (GND), U5.EPAD9_VIA5 (GND), U5.EPAD9_VIA6 (GND), U5.EPAD9_VIA7 (GND), U5.EPAD9_VIA8 (GND), U5.EPAD9_VIA9 (GND), U5.EPAD9_VIA10 (GND), U5.EPAD9_VIA11 (GND), U5.EPAD9_VIA12 (GND), U5.EPAD9_VIA13 (GND), U5.EPAD9_VIA14 (GND), U5.EPAD9_VIA15 (GND), U5.EPAD9_VIA16 (GND), U5.EPAD9_VIA17 (GND), U5.EPAD9_VIA18 (GND), U5.EPAD9_VIA19 (GND), U5.EPAD9_VIA20 (GND), U5.EPAD9_VIA21 (GND), U5.EPAD9_VIA22 (GND), U6.8 (GND), U6.21 (GND), U6.59 (GND), U6.EPAD9 (GND), U6.EPAD9_VIA1 (GND), U6.EPAD9_VIA2 (GND), U6.EPAD9_VIA3 (GND), U6.EPAD9_VIA4 (GND), U6.EPAD9_VIA5 (GND), U6.EPAD9_VIA6 (GND), U6.EPAD9_VIA7 (GND), U6.EPAD9_VIA8 (GND), U6.EPAD9_VIA9 (GND), U6.EPAD9_VIA10 (GND), U6.EPAD9_VIA11 (GND), U6.EPAD9_VIA12 (GND), U6.EPAD9_VIA13 (GND), U6.EPAD9_VIA14 (GND), U6.EPAD9_VIA15 (GND), U6.EPAD9_VIA16 (GND), U6.EPAD9_VIA17 (GND), U6.EPAD9_VIA18 (GND), U6.EPAD9_VIA19 (GND), U6.EPAD9_VIA20 (GND), U6.EPAD9_VIA21 (GND), U6.EPAD9_VIA22 (GND), U7.8 (GND), U7.21 (GND), U7.59 (GND), U7.EPAD9 (GND), U7.EPAD9_VIA1 (GND), U7.EPAD9_VIA2 (GND), U7.EPAD9_VIA3 (GND), U7.EPAD9_VIA4 (GND), U7.EPAD9_VIA5 (GND), U7.EPAD9_VIA6 (GND), U7.EPAD9_VIA7 (GND), U7.EPAD9_VIA8 (GND), U7.EPAD9_VIA9 (GND), U7.EPAD9_VIA10 (GND), U7.EPAD9_VIA11 (GND), U7.EPAD9_VIA12 (GND), U7.EPAD9_VIA13 (GND), U7.EPAD9_VIA14 (GND), U7.EPAD9_VIA15 (GND), U7.EPAD9_VIA16 (GND), U7.EPAD9_VIA17 (GND), U7.EPAD9_VIA18 (GND), U7.EPAD9_VIA19 (GND)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; also elsewhere on the board
unnamed: TP14.P$1, U8.64 (OSCOUT)
unnamed: BUSY1.+, RN4.8 (2)
unnamed: CN5.2, R17.1
unnamed: C39.2, R17.2, U5.18 (SW)
unnamed: C40.2, R18.2, U6.18 (SW)
unnamed: CN6.2, R18.1
unnamed: C69.2, R23.2, U7.18 (SW)
unnamed: CN9.2, R23.1
unnamed: FLAG1.+, RN4.7 (2)
unnamed: C70.2, R24.2, U8.18 (SW)
unnamed: C41.2, D3.3 (COM)
unnamed: C41.1, U5.57 (CP)
unnamed: CN10.2, R24.1
unnamed: BUSY2.+, RN4.6 (2)
unnamed: FLAG2.+, RN4.5 (2)
unnamed: FLAG1.-, U5.16 (!FLAG)
unnamed: BUSY1.-, U5.15 (!BUSY!/SYNC)
unnamed: R20.1, U5.9 (SENSEB_S), U5.77 (SENSEB_P), U5.82 (SENSEB_P)
unnamed: R19.1, U5.20 (SENSEA_S), U5.34 (SENSEA_P), U5.39 (SENSEA_P)
unnamed: CN7.1, J3.1, U5.38 (OUTA1), U5.42 (OUTA1), U5.53 (OUTA1), U5.EPAD4 (OUTA1), U5.EPAD4_VIA1 (OUTA1), U5.EPAD4_VIA2 (OUTA1), U5.EPAD4_VIA3 (OUTA1), U5.EPAD4_VIA4 (OUTA1), U5.EPAD4_VIA5 (OUTA1), U5.EPAD4_VIA6 (OUTA1), U5.EPAD4_VIA7 (OUTA1), U5.EPAD4_VIA8 (OUTA1)
unnamed: CN7.2, J3.2, U5.22 (OUTA2), U5.33 (OUTA2), U5.37 (OUTA2), U5.EPAD3 (OUTA2), U5.EPAD3_VIA1 (OUTA2), U5.EPAD3_VIA2 (OUTA2), U5.EPAD3_VIA3 (OUTA2), U5.EPAD3_VIA4 (OUTA2), U5.EPAD3_VIA5 (OUTA2), U5.EPAD3_VIA6 (OUTA2), U5.EPAD3_VIA7 (OUTA2), U5.EPAD3_VIA8 (OUTA2)
unnamed: TP7.P$1, U5.14 (SDO), U6.12 (SDI)
unnamed: CN7.3, J3.3, U5.7 (OUTB2), U5.81 (OUTB2), U5.85 (OUTB2), U5.EPAD8 (OUTB2), U5.EPAD8_VIA1 (OUTB2), U5.EPAD8_VIA2 (OUTB2), U5.EPAD8_VIA3 (OUTB2), U5.EPAD8_VIA4 (OUTB2), U5.EPAD8_VIA5 (OUTB2), U5.EPAD8_VIA6 (OUTB2), U5.EPAD8_VIA7 (OUTB2), U5.EPAD8_VIA8 (OUTB2)
unnamed: CN7.4, J3.4, U5.65 (OUTB1), U5.76 (OUTB1), U5.80 (OUTB1), U5.EPAD7 (OUTB1), U5.EPAD7_VIA1 (OUTB1), U5.EPAD7_VIA2 (OUTB1), U5.EPAD7_VIA3 (OUTB1), U5.EPAD7_VIA4 (OUTB1), U5.EPAD7_VIA5 (OUTB1), U5.EPAD7_VIA6 (OUTB1), U5.EPAD7_VIA7 (OUTB1), U5.EPAD7_VIA8 (OUTB1)
unnamed: C42.2, D4.3 (COM)
unnamed: C42.1, U6.57 (CP)
unnamed: BUSY3.+, RN5.8 (2)
unnamed: FLAG3.+, RN5.7 (2)
unnamed: FLAG2.-, U6.16 (!FLAG)
unnamed: BUSY2.-, U6.15 (!BUSY!/SYNC)
unnamed: R22.1, U6.9 (SENSEB_S), U6.77 (SENSEB_P), U6.82 (SENSEB_P)
unnamed: R21.1, U6.20 (SENSEA_S), U6.34 (SENSEA_P), U6.39 (SENSEA_P)
unnamed: TP12.P$1, U6.64 (OSCOUT), U7.63 (OSCIN)
unnamed: CN8.1, J4.1, U6.38 (OUTA1), U6.42 (OUTA1), U6.53 (OUTA1), U6.EPAD4 (OUTA1), U6.EPAD4_VIA1 (OUTA1), U6.EPAD4_VIA2 (OUTA1), U6.EPAD4_VIA3 (OUTA1), U6.EPAD4_VIA4 (OUTA1), U6.EPAD4_VIA5 (OUTA1), U6.EPAD4_VIA6 (OUTA1), U6.EPAD4_VIA7 (OUTA1), U6.EPAD4_VIA8 (OUTA1)
unnamed: CN8.2, J4.2, U6.22 (OUTA2), U6.33 (OUTA2), U6.37 (OUTA2), U6.EPAD3 (OUTA2), U6.EPAD3_VIA1 (OUTA2), U6.EPAD3_VIA2 (OUTA2), U6.EPAD3_VIA3 (OUTA2), U6.EPAD3_VIA4 (OUTA2), U6.EPAD3_VIA5 (OUTA2), U6.EPAD3_VIA6 (OUTA2), U6.EPAD3_VIA7 (OUTA2), U6.EPAD3_VIA8 (OUTA2)
unnamed: CN8.3, J4.3, U6.7 (OUTB2), U6.81 (OUTB2), U6.85 (OUTB2), U6.EPAD8 (OUTB2), U6.EPAD8_VIA1 (OUTB2), U6.EPAD8_VIA2 (OUTB2), U6.EPAD8_VIA3 (OUTB2), U6.EPAD8_VIA4 (OUTB2), U6.EPAD8_VIA5 (OUTB2), U6.EPAD8_VIA6 (OUTB2), U6.EPAD8_VIA7 (OUTB2), U6.EPAD8_VIA8 (OUTB2)
unnamed: CN8.4, J4.4, U6.65 (OUTB1), U6.76 (OUTB1), U6.80 (OUTB1), U6.EPAD7 (OUTB1), U6.EPAD7_VIA1 (OUTB1), U6.EPAD7_VIA2 (OUTB1), U6.EPAD7_VIA3 (OUTB1), U6.EPAD7_VIA4 (OUTB1), U6.EPAD7_VIA5 (OUTB1), U6.EPAD7_VIA6 (OUTB1), U6.EPAD7_VIA7 (OUTB1), U6.EPAD7_VIA8 (OUTB1)
unnamed: BUSY4.+, RN5.6 (2)
unnamed: C82.1, D5.2 (C2), U7.56 (VBOOT)
unnamed: C71.2, D5.3 (COM)
unnamed: C71.1, U7.57 (CP)
unnamed: FLAG4.+, RN5.5 (2)
unnamed: CN11.4, J5.4, U7.65 (OUTB1), U7.76 (OUTB1), U7.80 (OUTB1), U7.EPAD7 (OUTB1), U7.EPAD7_VIA1 (OUTB1), U7.EPAD7_VIA2 (OUTB1), U7.EPAD7_VIA3 (OUTB1), U7.EPAD7_VIA4 (OUTB1), U7.EPAD7_VIA5 (OUTB1), U7.EPAD7_VIA6 (OUTB1), U7.EPAD7_VIA7 (OUTB1), U7.EPAD7_VIA8 (OUTB1)
unnamed: FLAG3.-, U7.16 (!FLAG)
unnamed: BUSY3.-, U7.15 (!BUSY!/SYNC)
unnamed: R26.1, U7.9 (SENSEB_S), U7.77 (SENSEB_P), U7.82 (SENSEB_P)
unnamed: R25.1, U7.20 (SENSEA_S), U7.34 (SENSEA_P), U7.39 (SENSEA_P)
unnamed: TP8.P$1, U6.14 (SDO), U7.12 (SDI)
unnamed: CN11.1, J5.1, U7.38 (OUTA1), U7.42 (OUTA1), U7.53 (OUTA1), U7.EPAD4 (OUTA1), U7.EPAD4_VIA1 (OUTA1), U7.EPAD4_VIA2 (OUTA1), U7.EPAD4_VIA3 (OUTA1), U7.EPAD4_VIA4 (OUTA1), U7.EPAD4_VIA5 (OUTA1), U7.EPAD4_VIA6 (OUTA1), U7.EPAD4_VIA7 (OUTA1), U7.EPAD4_VIA8 (OUTA1)
unnamed: CN11.2, J5.2, U7.22 (OUTA2), U7.33 (OUTA2), U7.37 (OUTA2), U7.EPAD3 (OUTA2), U7.EPAD3_VIA1 (OUTA2), U7.EPAD3_VIA2 (OUTA2), U7.EPAD3_VIA3 (OUTA2), U7.EPAD3_VIA4 (OUTA2), U7.EPAD3_VIA5 (OUTA2), U7.EPAD3_VIA6 (OUTA2), U7.EPAD3_VIA7 (OUTA2), U7.EPAD3_VIA8 (OUTA2)
unnamed: CN11.3, J5.3, U7.7 (OUTB2), U7.81 (OUTB2), U7.85 (OUTB2), U7.EPAD8 (OUTB2), U7.EPAD8_VIA1 (OUTB2), U7.EPAD8_VIA2 (OUTB2), U7.EPAD8_VIA3 (OUTB2), U7.EPAD8_VIA4 (OUTB2), U7.EPAD8_VIA5 (OUTB2), U7.EPAD8_VIA6 (OUTB2), U7.EPAD8_VIA7 (OUTB2), U7.EPAD8_VIA8 (OUTB2)
unnamed: CN12.4, J6.4, U8.65 (OUTB1), U8.76 (OUTB1), U8.80 (OUTB1), U8.EPAD7 (OUTB1), U8.EPAD7_VIA1 (OUTB1), U8.EPAD7_VIA2 (OUTB1), U8.EPAD7_VIA3 (OUTB1), U8.EPAD7_VIA4 (OUTB1), U8.EPAD7_VIA5 (OUTB1), U8.EPAD7_VIA6 (OUTB1), U8.EPAD7_VIA7 (OUTB1), U8.EPAD7_VIA8 (OUTB1)
unnamed: CN12.3, J6.3, U8.7 (OUTB2), U8.81 (OUTB2), U8.85 (OUTB2), U8.EPAD8 (OUTB2), U8.EPAD8_VIA1 (OUTB2), U8.EPAD8_VIA2 (OUTB2), U8.EPAD8_VIA3 (OUTB2), U8.EPAD8_VIA4 (OUTB2), U8.EPAD8_VIA5 (OUTB2), U8.EPAD8_VIA6 (OUTB2), U8.EPAD8_VIA7 (OUTB2), U8.EPAD8_VIA8 (OUTB2)
unnamed: C84.1, D6.2 (C2), U8.56 (VBOOT)
unnamed: C72.2, D6.3 (COM)
unnamed: C72.1, U8.57 (CP)
unnamed: FLAG4.-, U8.16 (!FLAG)
unnamed: BUSY4.-, U8.15 (!BUSY!/SYNC)
unnamed: R28.1, U8.9 (SENSEB_S), U8.77 (SENSEB_P), U8.82 (SENSEB_P)
unnamed: R27.1, U8.20 (SENSEA_S), U8.34 (SENSEA_P), U8.39 (SENSEA_P)
unnamed: CN12.1, J6.1, U8.38 (OUTA1), U8.42 (OUTA1), U8.53 (OUTA1), U8.EPAD4 (OUTA1), U8.EPAD4_VIA1 (OUTA1), U8.EPAD4_VIA2 (OUTA1), U8.EPAD4_VIA3 (OUTA1), U8.EPAD4_VIA4 (OUTA1), U8.EPAD4_VIA5 (OUTA1), U8.EPAD4_VIA6 (OUTA1), U8.EPAD4_VIA7 (OUTA1), U8.EPAD4_VIA8 (OUTA1)
unnamed: CN12.2, J6.2, U8.22 (OUTA2), U8.33 (OUTA2), U8.37 (OUTA2), U8.EPAD3 (OUTA2), U8.EPAD3_VIA1 (OUTA2), U8.EPAD3_VIA2 (OUTA2), U8.EPAD3_VIA3 (OUTA2), U8.EPAD3_VIA4 (OUTA2), U8.EPAD3_VIA5 (OUTA2), U8.EPAD3_VIA6 (OUTA2), U8.EPAD3_VIA7 (OUTA2), U8.EPAD3_VIA8 (OUTA2)
unnamed: Q3.3 (OUT), TP10.P$1, U5.63 (OSCIN)
unnamed: TP11.P$1, U5.64 (OSCOUT), U6.63 (OSCIN)
unnamed: TP13.P$1, U7.64 (OSCOUT), U8.63 (OSCIN)
unnamed: TP9.P$1, U7.14 (SDO), U8.12 (SDI)
POWERSTEP_CS: U5.10 (!CS), U6.10 (!CS), U7.10 (!CS), U8.10 (!CS); also elsewhere on the board
POWERSTEP_MISO: U8.14 (SDO); also elsewhere on the board
POWERSTEP_MOSI: U5.12 (SDI); also elsewhere on the board
POWERSTEP_RESET: U5.19 (!STBY!/!RESET), U6.19 (!STBY!/!RESET), U7.19 (!STBY!/!RESET), U8.19 (!STBY!/!RESET); also elsewhere on the board
POWERSTEP_SCK: U5.11 (CK), U6.11 (CK), U7.11 (CK), U8.11 (CK); also elsewhere on the board
VBOOT_1: C52.1, D3.2 (C2), U5.56 (VBOOT)
VBOOT_2: C54.1, D4.2 (C2), U6.56 (VBOOT)
VCC_1: C55.1, C61.2, U5.58 (VCC), U5.60 (VCCREG)
VCC_2: C56.1, C62.2, U6.58 (VCC), U6.60 (VCCREG)
VCC_3: C85.1, C91.2, U7.58 (VCC), U7.60 (VCCREG)
VCC_4: C86.1, C92.2, U8.58 (VCC), U8.60 (VCCREG)
VDDIO_1: C45.1, C65.2, C67.2, RN4.1, RN4.2 (1), U5.13 (VDDIO), U5.62 (VREG)
VDDIO_2: C46.1, C66.2, C68.2, RN4.3 (1), RN4.4 (1), U6.13 (VDDIO), U6.62 (VREG)
VDDIO_3: C75.1, C95.2, C97.2, RN5.1, RN5.2 (1), U7.13 (VDDIO), U7.62 (VREG)
VDDIO_4: C76.1, C96.2, C98.2, RN5.3 (1), RN5.4 (1), U8.13 (VDDIO), U8.62 (VREG)
VIN: C43.2, C44.2, C47.2, C48.2, C49.2, C50.2, C51.2, C52.2, C53.2, C54.2, C57.2, C58.2, C59.+, C60.+, C63.+, C64.+, C73.2, C74.2, C77.2, C78.2, C79.2, C80.2, C81.2, C82.2, C83.2, C84.2, C87.2, C88.2, C89.+, C90.+, C93.+, C94.+, D3.1 (A1), D4.1 (A1), D5.1 (A1), D6.1 (A1), U5.1 (VS), U5.23 (VS), U5.43 (VS), U5.55 (VS), U5.61 (VSREG), U5.66 (VS), U6.1 (VS), U6.23 (VS), U6.43 (VS), U6.55 (VS), U6.61 (VSREG), U6.66 (VS), U7.1 (VS), U7.23 (VS), U7.43 (VS), U7.55 (VS), U7.61 (VSREG), U7.66 (VS), U8.1 (VS), U8.23 (VS), U8.43 (VS), U8.55 (VS), U8.61 (VSREG), U8.66 (VS); also elsewhere on the board

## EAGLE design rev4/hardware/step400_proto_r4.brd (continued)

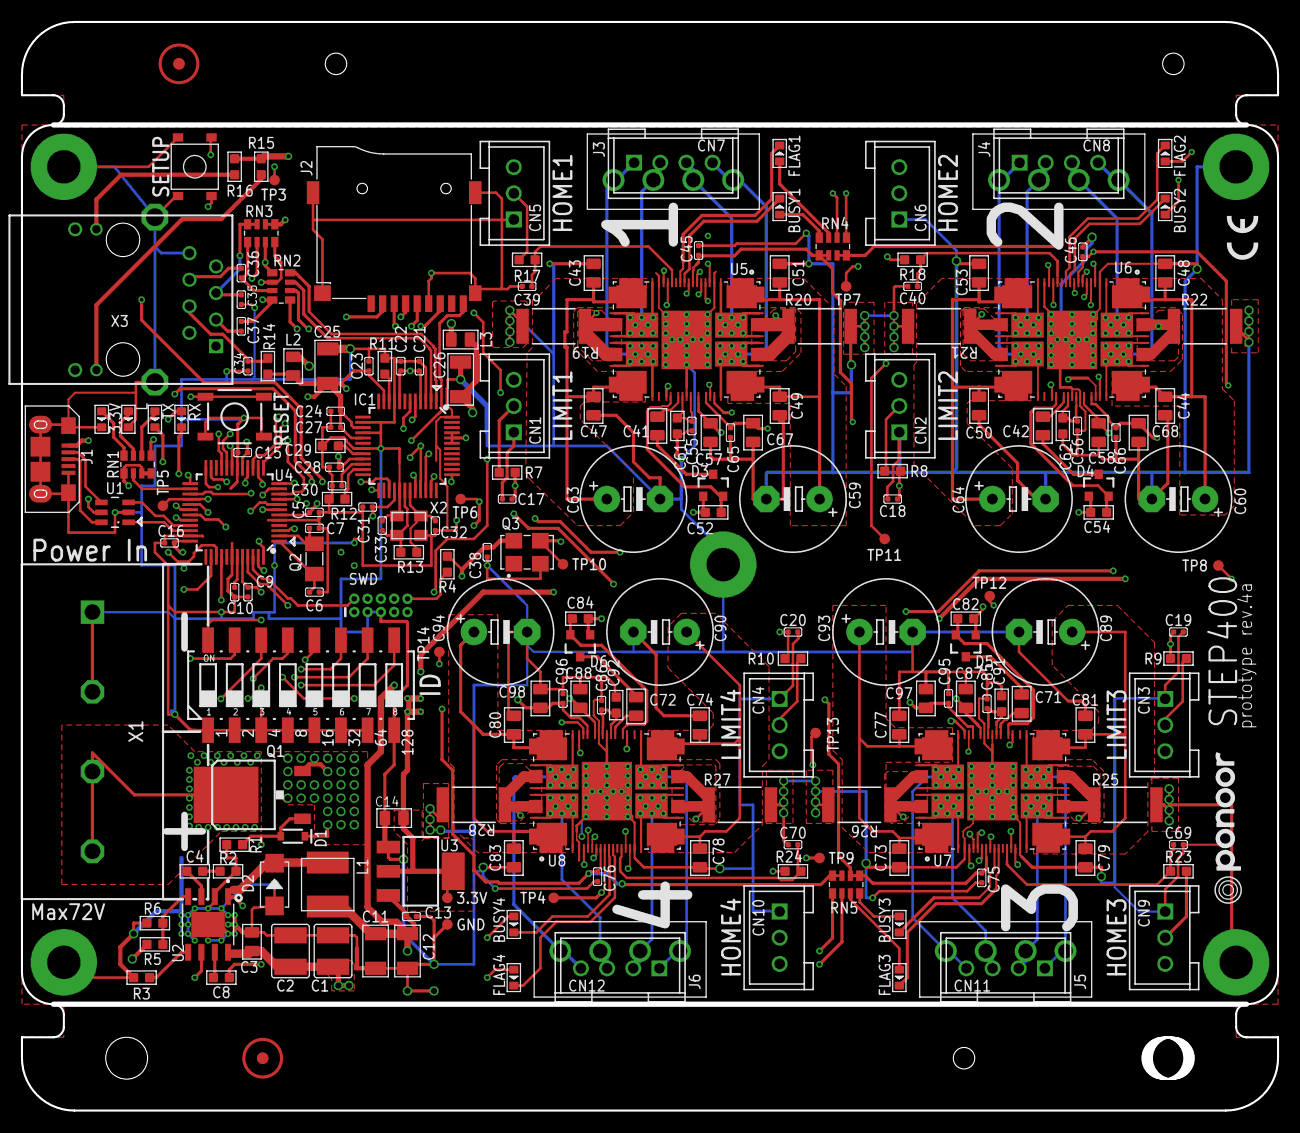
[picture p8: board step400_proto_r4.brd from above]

Board: 4 copper layers, 120.0 x 104.0 mm, 212 parts (0 on the bottom side), 158 nets.

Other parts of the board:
U$1: PONOOR_TEXT_15MM
U$2, U$3: FIDUCIAL_MARKER_PBAN
U$4: CE_3MM

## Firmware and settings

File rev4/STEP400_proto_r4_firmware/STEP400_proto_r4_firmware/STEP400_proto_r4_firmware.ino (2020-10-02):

/*
 Name:		STEP400_proto_r4_firmware.ino

 target:    Arduino Zero
 Created:   2020/04/08 10:24:41
 Author:    kanta
*/

#include "wiring_private.h" // pinPeripheral() function
#include <SPI.h>
#include <OSCMessage.h>
#include <Ethernet.h>
#include <Ponoor_PowerSTEP01Library.h>
#include <SD.h>
#include <ArduinoJson.h>
#include <Adafruit_SleepyDog.h>

#define COMPILE_DATE __DATE__
#define COMPILE_TIME __TIME__
constexpr auto FIRMWARE_NAME = "STEP400proto_r4";
boolean debugMode = false;

// Json configuration file
const char* filename = "/config.txt";
//char configName[64];
String configName;
bool sdInitializeSucceeded = false;
bool configFileOpenSucceeded = false;
bool configFileParseSucceeded = false;

// pins
#define ledPin	13u
const uint8_t dipSwPin[8] = { A5,SCL,7u,SDA,2u,9u,3u,0u };
const uint8_t limitSwPin[4] = { 1u,5u,8u,A1 };
#define SD_CS_PIN	4u
#define SD_DETECT_PIN   A4
#define SETUP_SW_PIN    31u

#define NUM_OF_MOTOR   (4)
#define POWERSTEP_MISO	6u	// D6 /SERCOM3/PAD[2] miso
#define POWERSTEP_MOSI	11u	// D11/SERCOM3/PAD[0] mosi
#define POWERSTEP_SCK	12u	// D12/SERCOM3/PAD[3] sck
SPIClass powerStepSPI(&sercom3, POWERSTEP_MISO, POWERSTEP_SCK, POWERSTEP_MOSI, SPI_PAD_0_SCK_3, SERCOM_RX_PAD_2);// MISO/SCK/MOSI pins

#define POWERSTEP_CS_PIN A0
#define POWERSTEP_RESET_PIN A2
powerSTEP stepper[] = {
    powerSTEP(3, POWERSTEP_CS_PIN, POWERSTEP_RESET_PIN),
    powerSTEP(2, POWERSTEP_CS_PIN, POWERSTEP_RESET_PIN),
    powerSTEP(1, POWERSTEP_CS_PIN, POWERSTEP_RESET_PIN),
    powerSTEP(0, POWERSTEP_CS_PIN, POWERSTEP_RESET_PIN)
};

#define MOTOR_ID_ALL    255
#define MOTOR_ID_FIRST  1
#define MOTOR_ID_LAST   4

#define TVAL_LIMIT_VAL  64 // approx. 5A
// KVAL and TVAL storage.
uint8_t kvalHold[NUM_OF_MOTOR], kvalRun[NUM_OF_MOTOR], kvalAcc[NUM_OF_MOTOR], kvalDec[NUM_OF_MOTOR];
uint8_t tvalHold[NUM_OF_MOTOR], tvalRun[NUM_OF_MOTOR], tvalAcc[NUM_OF_MOTOR], tvalDec[NUM_OF_MOTOR];
bool isCurrentMode[NUM_OF_MOTOR];;

// Network
byte mac[] = { 0x60, 0x95, 0xCE, 0x10, 0x02, 0x00 },
    myId = 0;
IPAddress 
    myIp(10, 0, 0, 100),
    destIp(10, 0, 0, 10),
    dns(10, 0, 0, 1),
    gateway(10, 0, 0, 1),
    subnet(255, 255, 255, 0);
unsigned int outPort;
unsigned int inPort;
EthernetUDP Udp;
boolean
    isDestIpSet,
    isMyIpAddId,
    isMacAddId,
    isOutPortAddId,
    bootedMsgEnable;
boolean isWaitingSendBootMsg = false;
#define BOOT_MSG_WAIT_TIME  1000    //[ms], The waiting duration for sending a boot message after Ethernet has been linked

#define W5500_RESET_PIN A3

#define STATUS_POLL_PERIOD   1 // [ms]

// these values will be initialized at loadConfig()
bool busy[NUM_OF_MOTOR];
bool flag[NUM_OF_MOTOR];
bool HiZ[NUM_OF_MOTOR];
bool homeSwState[NUM_OF_MOTOR];
bool dir[NUM_OF_MOTOR];
bool uvloStatus[NUM_OF_MOTOR];
uint8_t motorStatus[NUM_OF_MOTOR];
uint8_t thermalStatus[NUM_OF_MOTOR];

bool reportBUSY[NUM_OF_MOTOR];
bool reportFLAG[NUM_OF_MOTOR];
bool reportHiZ[NUM_OF_MOTOR];
bool reportHomeSwStatus[NUM_OF_MOTOR];
bool reportDir[NUM_OF_MOTOR];
bool reportMotorStatus[NUM_OF_MOTOR];

bool reportSwEvn[NUM_OF_MOTOR];
bool reportCommandError[NUM_OF_MOTOR];
bool reportUVLO[NUM_OF_MOTOR];
bool reportThermalStatus[NUM_OF_MOTOR];
bool reportOCD[NUM_OF_MOTOR];
bool reportStall[NUM_OF_MOTOR];

bool limitSwState[NUM_OF_MOTOR];
bool reportLimitSwStatus[NUM_OF_MOTOR];
bool limitSwMode[NUM_OF_MOTOR];

// Init value storages
bool homeSwMode[NUM_OF_MOTOR];

uint16_t intersectSpeed[NUM_OF_MOTOR]; // INT_SPEED
uint8_t 
    startSlope[NUM_OF_MOTOR], // ST_SLP
    accFinalSlope[NUM_OF_MOTOR], // FN_SLP_ACC
    decFinalSlope[NUM_OF_MOTOR], // FN_SLP_DEC
    stallThreshold[NUM_OF_MOTOR]; // STALL_TH
uint8_t
    fastDecaySetting[NUM_OF_MOTOR], // T_FAST
    minOnTime[NUM_OF_MOTOR], // TON_MIN
    minOffTime[NUM_OF_MOTOR]; // TOFF_MIN
uint8_t
    overCurrentThreshold[NUM_OF_MOTOR], // OCD
    microStepMode[NUM_OF_MOTOR]; // STEP_MODE
uint16_t slewRate[NUM_OF_MOTOR]; // GATECFG1
uint8_t slewRateNum[NUM_OF_MOTOR]; // [0]114, [1]220, [2]400, [3]520, [4]790, [5]980.
float lowSpeedOptimize[NUM_OF_MOTOR];
bool electromagnetBrakeEnable[NUM_OF_MOTOR];

float
    acc[NUM_OF_MOTOR],
    dec[NUM_OF_MOTOR],
    maxSpeed[NUM_OF_MOTOR],
    fullStepSpeed[NUM_OF_MOTOR];

// servo mode
uint32_t lastServoUpdateTime;
int32_t targetPosition[NUM_OF_MOTOR]; // these values will be initialized at setup()
float kP[NUM_OF_MOTOR], kI[NUM_OF_MOTOR], kD[NUM_OF_MOTOR];
boolean isServoMode[NUM_OF_MOTOR];
constexpr auto position_tolerance = 0; // steps

// Tx, Rx LED
bool rxLedEnabled = false, txLedEnabled = false;
uint32_t RXL_blinkStartTime, TXL_blinkStartTime;
#define RXL_TXL_BLINK_DURATION	30 // ms

void setup() {
    //setUSBPriority();
    pinMode(ledPin, OUTPUT);
    pinMode(SD_CS_PIN, OUTPUT);
    pinMode(W5500_RESET_PIN, OUTPUT);
    pinMode(SD_DETECT_PIN, INPUT_PULLUP);
    pinMode(SETUP_SW_PIN, INPUT_PULLUP);

    for (auto i=0; i < NUM_OF_MOTOR; i++)
    {
        pinMode(limitSwPin[i], INPUT_PULLUP);
    }

    pinMode(POWERSTEP_RESET_PIN, OUTPUT);
    pinMode(POWERSTEP_CS_PIN, OUTPUT);
    pinMode(POWERSTEP_MOSI, OUTPUT);
    pinMode(POWERSTEP_MISO, INPUT);
    pinMode(POWERSTEP_SCK, OUTPUT);
    digitalWrite(POWERSTEP_RESET_PIN, HIGH);
    digitalWrite(POWERSTEP_RESET_PIN, LOW);
    delay(10);
    digitalWrite(POWERSTEP_RESET_PIN, HIGH);
    digitalWrite(POWERSTEP_CS_PIN, HIGH);
    powerStepSPI.begin();
    pinPeripheral(POWERSTEP_MOSI, PIO_SERCOM_ALT);
    pinPeripheral(POWERSTEP_SCK, PIO_SERCOM_ALT);
    pinPeripheral(POWERSTEP_MISO, PIO_SERCOM_ALT);
    powerStepSPI.setDataMode(SPI_MODE3);
    
    loadConfig();
    for (uint8_t i = 0; i < NUM_OF_MOTOR; i++)
    {
        stepper[i].SPIPortConnect(&powerStepSPI);
        resetMotorDriver(i + MOTOR_ID_FIRST);
        digitalWrite(ledPin, HIGH);
        delay(5);
        digitalWrite(ledPin, LOW);
        delay(5);
    }

    // Configure W5500
    digitalWrite(W5500_RESET_PIN, HIGH);
    myId = getMyId();
    delay(1);
    resetEthernet();
    isWaitingSendBootMsg = bootedMsgEnable;

    SerialUSB.begin(9600);
    Watchdog.enable(100);
}

void sendBootMsg(uint32_t _currentTime) {
    static uint32_t linkedTime;
    if ( Ethernet.linkStatus() == LinkOFF ) {
        linkedTime = _currentTime;
        return; 
    }
    else {
        if ((uint32_t)(_currentTime - linkedTime) < BOOT_MSG_WAIT_TIME) return;
    }
    IPAddress broadcastIp;
    for (uint8_t i = 0; i < 3; i++)
    {
        broadcastIp[i] = destIp[i];
    }
    broadcastIp[3] = 255;
    OSCMessage newMes("/booted");
    newMes.add(myId);
    Udp.beginPacket(broadcastIp, outPort);
    newMes.send(Udp);
    Udp.endPacket();
    newMes.empty();
    turnOnTXL();
    isWaitingSendBootMsg = false;
}

uint8_t getMyId() {
    uint8_t _id = 0;
    for (auto i = 0; i < 8; ++i)
    {
        pinMode(dipSwPin[i], INPUT_PULLUP);
        _id |= (!digitalRead(dipSwPin[i])) << i;
    }
    return _id;
}

void resetEthernet() {
    digitalWrite(W5500_RESET_PIN, LOW);
    digitalWrite(ledPin, HIGH);
    delay(10); // This delay is necessary to refresh the network connection.
    digitalWrite(W5500_RESET_PIN, HIGH);
    digitalWrite(ledPin, LOW);
    delay(1);
    if ( isMyIpAddId ) myIp[3] += myId;
    if ( isMacAddId ) mac[5] += myId;
    if ( isOutPortAddId ) outPort += myId;
    Ethernet.begin(mac, myIp, dns, gateway, subnet);
    Udp.begin(inPort);
}

void resetMotorDriver(uint8_t deviceID) {
    if (MOTOR_ID_FIRST <= deviceID && deviceID <= MOTOR_ID_LAST) {
        deviceID -= MOTOR_ID_FIRST;
        stepper[deviceID].resetDev();
        stepper[deviceID].configStepMode(microStepMode[deviceID]);
        stepper[deviceID].setMaxSpeed(maxSpeed[deviceID]);
        stepper[deviceID].setLoSpdOpt(true);
        stepper[deviceID].setMinSpeed(lowSpeedOptimize[deviceID]); // Low speed optimazation threshold
        stepper[deviceID].setFullSpeed(fullStepSpeed[deviceID]);
        stepper[deviceID].setParam(INT_SPD, intersectSpeed[deviceID]);
        stepper[deviceID].setParam(ST_SLP, startSlope[deviceID]);
        stepper[deviceID].setParam(FN_SLP_ACC, accFinalSlope[deviceID]);
        stepper[deviceID].setParam(FN_SLP_DEC, decFinalSlope[deviceID]);
        stepper[deviceID].setAcc(acc[deviceID]);
        stepper[deviceID].setDec(dec[deviceID]);
        stepper[deviceID].setSlewRate(slewRate[deviceID]);
        stepper[deviceID].setPWMFreq(PWM_DIV_1, PWM_MUL_0_75);
        uint16_t swMode = homeSwMode[deviceID] ? SW_USER : SW_HARD_STOP;
        stepper[deviceID].setSwitchMode(swMode);//
        stepper[deviceID].setVoltageComp(VS_COMP_DISABLE);
        stepper[deviceID].setOCThreshold(overCurrentThreshold[deviceID]); // 5A for 0.1ohm shunt resistor
        stepper[deviceID].setOCShutdown(OC_SD_ENABLE);
        stepper[deviceID].setOscMode(EXT_16MHZ_OSCOUT_INVERT);
        stepper[deviceID].setRunKVAL(kvalRun[deviceID]);
        stepper[deviceID].setAccKVAL(kvalAcc[deviceID]);
        stepper[deviceID].setDecKVAL(kvalDec[deviceID]);
        stepper[deviceID].setHoldKVAL(kvalHold[deviceID]);
        stepper[deviceID].setParam(STALL_TH, stallThreshold[deviceID]);
        stepper[deviceID].setParam(ALARM_EN, 0xEF); // Enable alarms except ADC UVLO
        //kvalHold[deviceID] = tvalHold[deviceID] = stepper[deviceID].getHoldKVAL();
        //kvalRun[deviceID] = tvalRun[deviceID] = stepper[deviceID].getRunKVAL();
        //kvalAcc[deviceID] = tvalAcc[deviceID] = stepper[deviceID].getAccKVAL();
        //kvalDec[deviceID] = tvalDec[deviceID] = stepper[deviceID].getDecKVAL();

        delay(1);
        stepper[deviceID].getStatus(); // clears error flags
    }
}

void turnOnRXL() {
    digitalWrite(PIN_LED_RXL, LOW); // turn on
    RXL_blinkStartTime = millis();
    rxLedEnabled = true;
}

void turnOnTXL() {
    digitalWrite(PIN_LED_TXL, LOW); // turn on
    TXL_blinkStartTime = millis();
    txLedEnabled = true;
}

void sendOneInt(String address, int32_t data) {
    if (!isDestIpSet) { return; }
    OSCMessage newMes(address.c_str());
    newMes.add((int32_t)data);
    Udp.beginPacket(destIp, outPort);
    newMes.send(Udp);
    Udp.endPacket();
    newMes.empty();
    turnOnTXL();
}

void sendTwoInt(String address, int32_t data1, int32_t data2) {
    if (!isDestIpSet) { return; }
    OSCMessage newMes(address.c_str());
    newMes.add(data1).add(data2);
    Udp.beginPacket(destIp, outPort);
    newMes.send(Udp);
    Udp.endPacket();
    newMes.empty();
    turnOnTXL();
}

void sendThreeInt(String address, int32_t data1, int32_t data2, int32_t data3) {
    if (!isDestIpSet) { return; }
    OSCMessage newMes(address.c_str());
    newMes.add(data1).add(data2).add(data3);
    Udp.beginPacket(destIp, outPort);
    newMes.send(Udp);
    Udp.endPacket();
    newMes.empty();
    turnOnTXL();
}

void sendIdFloat(String address, int32_t id, float data) {
    if (!isDestIpSet) { return; }
    OSCMessage newMes(address.c_str());
    newMes.add(id).add(data);
    Udp.beginPacket(destIp, outPort);
    newMes.send(Udp);
    Udp.endPacket();
    newMes.empty();
    turnOnTXL();
}

void sendOneString(String address, const char* data) {
    if (!isDestIpSet) { return; }
    OSCMessage newMes(address.c_str());
    newMes.add(data);
    Udp.beginPacket(destIp, outPort);
    newMes.send(Udp);
    Udp.endPacket();
    newMes.empty();
    turnOnTXL();
}

void sendStatusDebug(String address, int32_t data1, int32_t data2, int32_t data3){
    if (!isDestIpSet) { return; }
    OSCMessage newMes(address.c_str());
    newMes.add(data1).add(data2).add(data3);
    Udp.beginPacket(destIp, outPort);
    newMes.send(Udp);
    Udp.endPacket();
    newMes.empty();
}

void checkStatus() {
    uint32_t t;
    for (uint8_t i = 0; i < NUM_OF_MOTOR; i++)
    {
        const auto status = stepper[i].getStatus();
        // HiZ, high for HiZ
        t = (status & STATUS_HIZ) > 0;
        if (HiZ[i] != t)
        {
            HiZ[i] = t;
            if (reportHiZ[i]) sendTwoInt("/HiZ", i + MOTOR_ID_FIRST, t);
            if (debugMode) sendStatusDebug("/HiZ", i + MOTOR_ID_FIRST, t, status);
        }
        // BUSY, low for busy
        t = (status & STATUS_BUSY) == 0;
        if (busy[i] != t)
        {
        	busy[i] = t;
        	if ( reportBUSY[i] ) sendTwoInt("/busy", i + MOTOR_ID_FIRST, t);
            if (debugMode) sendStatusDebug("/busy", i + MOTOR_ID_FIRST, t, status);
        }
        // DIR
        t = (status & STATUS_DIR) > 0;
        if (dir[i] != t)
        {
            dir[i] = t;
            if (reportDir[i]) sendTwoInt("/dir", i + MOTOR_ID_FIRST, t);
            if (debugMode) sendStatusDebug("/dir", i + MOTOR_ID_FIRST, t, status);
        }
        // SW_F, low for open, high for close
        t = (status & STATUS_SW_F) > 0;
        if (homeSwState[i] != t)
        {
            homeSwState[i] = t;
            if (reportHomeSwStatus[i]) getHomeSw(i + 1);
            if (debugMode) sendStatusDebug("/homeSw", i + MOTOR_ID_FIRST, t, status);
        }
        // SW_EVN, active high, latched
        t = (status & STATUS_SW_EVN) > 0;
        if (t && reportSwEvn[i]) sendOneInt("/swEvent", i + MOTOR_ID_FIRST);
        if (debugMode && t) sendStatusDebug("/swEvent", i + MOTOR_ID_FIRST, t, status);
        // MOT_STATUS
        t = (status & STATUS_MOT_STATUS) >> 5;
        if (motorStatus[i] != t) {
            motorStatus[i] = t;
            if (reportMotorStatus[i]) sendTwoInt("/motorStatus", i + MOTOR_ID_FIRST, motorStatus[i]);
            if (debugMode) sendStatusDebug("/motorStatus", i + MOTOR_ID_FIRST, t, status);
        }
        // CMD_ERROR, active high, latched
        t = (status & STATUS_CMD_ERROR) > 0;
        if (t && reportCommandError[i]) sendOneInt("commandError", i + MOTOR_ID_FIRST);
        if (debugMode && t) sendStatusDebug("/commandError", i + MOTOR_ID_FIRST, t, status);
        // UVLO, active low
        t = (status & STATUS_UVLO) == 0;
        if (t != uvloStatus[i])
        {
            uvloStatus[i] = !uvloStatus[i];
            if (reportUVLO[i]) sendTwoInt("/uvlo", i + MOTOR_ID_FIRST, uvloStatus[i]);
            if (debugMode) sendStatusDebug("/ulvo", i + MOTOR_ID_FIRST, t, status);
        }
        // TH_STATUS
        t = (status & STATUS_TH_STATUS) >> 11;
        if (thermalStatus[i] != t) {
            thermalStatus[i] = t;
            if (reportThermalStatus[i]) sendTwoInt("/thermalStatus", i + MOTOR_ID_FIRST, thermalStatus[i]);
            if (debugMode) sendStatusDebug("/thermalStatus", i + MOTOR_ID_FIRST, t, status);
        }
        // OCD, active low, latched
        t = (status & STATUS_OCD) == 0;
        if (t && reportOCD[i]) sendOneInt("/overCurrent", i + 1);
        if (debugMode && t) sendStatusDebug("/overCurrent", i + MOTOR_ID_FIRST, t, status);

        // STALL A&B, active low, latched
        t = (status & (STATUS_STALL_A | STATUS_STALL_B)) >> 14;
        if ((t != 3) && reportStall[i]) sendOneInt("/stall", i + MOTOR_ID_FIRST);
        if (debugMode && (t != 3)) sendStatusDebug("/stall", i + MOTOR_ID_FIRST, t, status);
    }
}

void checkLimitSw() {
    for (uint8_t i = 0; i < NUM_OF_MOTOR; i++)
    {
        if (limitSwState[i] == digitalRead(limitSwPin[i]))
        {
            limitSwState[i] = !limitSwState[i];
            if ( limitSwState[i] && (limitSwMode[i] == SW_HARD_STOP) )
            {
                stepper[i].hardStop();
            }
            if (reportLimitSwStatus[i])
            {
                sendThreeInt("/limitSw", i + MOTOR_ID_FIRST, limitSwState[i], dir[i]);
            }
        }
    }
}

void checkSetupSw() {
    static boolean lastSetupSwState = false;
    if ( digitalRead(SETUP_SW_PIN) != lastSetupSwState )
    {
        lastSetupSwState = !lastSetupSwState;
        sendOneInt("/setupSw", !lastSetupSwState);
    }
}

void checkLED(uint32_t _currentTimeMillis) {
    if (rxLedEnabled)
    {
        if ((uint32_t)(_currentTimeMillis - RXL_blinkStartTime) >= RXL_TXL_BLINK_DURATION)
        {
            rxLedEnabled = false;
            digitalWrite(PIN_LED_RXL, HIGH); // turn off
        }
    }
    if (txLedEnabled)
    {
        if ((uint32_t)(_currentTimeMillis - TXL_blinkStartTime) >= RXL_TXL_BLINK_DURATION)
        {
            txLedEnabled = false;
            digitalWrite(PIN_LED_TXL, HIGH); // turn off
        }
    }
}

void updateServo(uint32_t currentTimeMicros) {
    static float eZ1[NUM_OF_MOTOR] = { 0,0,0,0 },
        eZ2[NUM_OF_MOTOR] = { 0,0,0,0 },
        integral[NUM_OF_MOTOR] = { 0,0,0,0 };
    float spd = 0.0;
    if ((uint32_t)(currentTimeMicros - lastServoUpdateTime) >= 100) {
        for (uint8_t i = 0; i < NUM_OF_MOTOR; i++) {
            if (isServoMode[i]) {
                int32_t error = targetPosition[i] - stepper[i].getPos();
                integral[i] += ((error + eZ1[i]) / 2.0f);
                if (integral[i] > 1500.0) integral[i] = 1500.0;
                else if (integral[i] < -1500.0) integral[i] = -1500.0;
                if (abs(error) > position_tolerance) {
                    double diff = error - eZ1[i];

                    spd = error * kP[i] + integral[i] * kI[i] + diff * kD[i];
                }
                eZ2[i] = eZ1[i];
                eZ1[i] = error;
                float absSpd = abs(spd);
                //if (absSpd < 1.) {
                //    spd = 0.0;
                //}
                stepper[i].run((spd > 0), absSpd);
            }
        }
        lastServoUpdateTime = currentTimeMicros;
    }
}

void loop() {
    uint32_t 
        currentTimeMillis = millis(),
        currentTimeMicros = micros();
    static uint32_t lastPollTime = 0;

    if ((uint32_t)(currentTimeMillis - lastPollTime) >= STATUS_POLL_PERIOD)
    {
        checkStatus();
        checkLimitSw();
        checkSetupSw();
        checkLED(currentTimeMillis);
        uint8_t t = getMyId();
        if (myId != t) {
            myId = t;
            resetEthernet();
        }
        Watchdog.reset();
        lastPollTime = currentTimeMillis;
    }
    if (SerialUSB.available() > 0)
    {
        diagnosis(SerialUSB.read());
    }
    if (isWaitingSendBootMsg) { sendBootMsg(currentTimeMillis); }
    OSCMsgReceive();
    updateServo(currentTimeMicros);
}

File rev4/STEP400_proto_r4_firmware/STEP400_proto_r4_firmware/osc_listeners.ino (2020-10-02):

void OSCMsgReceive() {
    bool bMsgHasError = false, bMsgRouted = false;
    OSCMessage msgIN;
    int size;
    if ((size = Udp.parsePacket()) > 0) {
        while (size--)
            msgIN.fill(Udp.read());

        bMsgHasError = msgIN.hasError();
        if (!bMsgHasError) {
            // some possible frequent messeages
            bMsgRouted |= msgIN.route("/setTargetPosition", setTargetPosition);
            bMsgRouted |= msgIN.route("/setTargetPositionList", setTargetPositionList);
            bMsgRouted |= msgIN.route("/getPosition", getPosition);
            bMsgRouted |= msgIN.route("/getSpeed", getSpeed);
            bMsgRouted |= msgIN.route("/run", run);
            bMsgRouted |= msgIN.route("/runRaw", runRaw);

            // motion
            bMsgRouted |= msgIN.route("/move", move);
            bMsgRouted |= msgIN.route("/goTo", goTo);
            bMsgRouted |= msgIN.route("/goToDir", goToDir);
            bMsgRouted |= msgIN.route("/goUntil", goUntil);
            bMsgRouted |= msgIN.route("/goUntilRaw", goUntilRaw);
            bMsgRouted |= msgIN.route("/releaseSw", releaseSw);
            bMsgRouted |= msgIN.route("/goHome", goHome);
            bMsgRouted |= msgIN.route("/goMark", goMark);
            bMsgRouted |= msgIN.route("/setMark", setMark);
            bMsgRouted |= msgIN.route("/getMark", getMark);
            bMsgRouted |= msgIN.route("/setPosition", setPosition);
            bMsgRouted |= msgIN.route("/resetPos", resetPos);
            bMsgRouted |= msgIN.route("/resetDev", resetDev);
            bMsgRouted |= msgIN.route("/softStop", softStop);
            bMsgRouted |= msgIN.route("/hardStop", hardStop);
            bMsgRouted |= msgIN.route("/softHiZ", softHiZ);
            bMsgRouted |= msgIN.route("/hardHiZ", hardHiZ);

            // servo mode
            bMsgRouted |= msgIN.route("/enableServoMode", enableServoMode);
            bMsgRouted |= msgIN.route("/setServoParam", setServoParam);
            bMsgRouted |= msgIN.route("/getServoParam", getServoParam);

            // speed
            bMsgRouted |= msgIN.route("/setSpeedProfile", setSpeedProfile);
            bMsgRouted |= msgIN.route("/setMaxSpeed", setMaxSpeed);
            bMsgRouted |= msgIN.route("/setFullstepSpeed", setFullstepSpeed);
            bMsgRouted |= msgIN.route("/getFullstepSpeed", getFullstepSpeed);
            bMsgRouted |= msgIN.route("/setAcc", setAcc);
            bMsgRouted |= msgIN.route("/setDec", setDec);
            bMsgRouted |= msgIN.route("/getSpeedProfile", getSpeedProfile);

            // Kval
            bMsgRouted |= msgIN.route("/setKval", setKval);
            bMsgRouted |= msgIN.route("/setAccKval", setAccKval);
            bMsgRouted |= msgIN.route("/setDecKval", setDecKval);
            bMsgRouted |= msgIN.route("/setRunKval", setRunKval);
            bMsgRouted |= msgIN.route("/setHoldKval", setHoldKval);
            bMsgRouted |= msgIN.route("/getKval", getKval);

            //TVAL
            bMsgRouted |= msgIN.route("/setTval", setTval);
            bMsgRouted |= msgIN.route("/setAccTval", setAccTval);
            bMsgRouted |= msgIN.route("/setDecTval", setDecTval);
            bMsgRouted |= msgIN.route("/setRunTval", setRunTval);
            bMsgRouted |= msgIN.route("/setHoldTval", setHoldTval);
            bMsgRouted |= msgIN.route("/getTval", getTval);
            bMsgRouted |= msgIN.route("/getTval_mA", getTval_mA);

            // config
            bMsgRouted |= msgIN.route("/setDestIp", setDestIp);
            bMsgRouted |= msgIN.route("/getVersion", getVersion);
            bMsgRouted |= msgIN.route("/getConfigName", getConfigName);
            bMsgRouted |= msgIN.route("/getConfigRegister", getConfigRegister);
            bMsgRouted |= msgIN.route("/getStatus", getStatus);
            bMsgRouted |= msgIN.route("/getStatusList", getStatusList);
            bMsgRouted |= msgIN.route("/getHomeSw", getHomeSw);
            bMsgRouted |= msgIN.route("/getBusy", getBusy);
            bMsgRouted |= msgIN.route("/getUvlo", getUvlo);
            bMsgRouted |= msgIN.route("/getMotorStatus", getMotorStatus);
            bMsgRouted |= msgIN.route("/getThermalStatus", getThermalStatus);
            bMsgRouted |= msgIN.route("/resetMotorDriver", resetMotorDriver);
            //bMsgRouted |= msgIN.route("/enableFlagReport", enableFlagReport);
            bMsgRouted |= msgIN.route("/enableBusyReport", enableBusyReport);
            bMsgRouted |= msgIN.route("/enableHizReport", enableHizReport);
            bMsgRouted |= msgIN.route("/enableHomeSwReport", enableHomeSwReport);
            bMsgRouted |= msgIN.route("/enableDirReport", enableDirReport);
            bMsgRouted |= msgIN.route("/enableMotorStatusReport", enableMotorStatusReport);
            bMsgRouted |= msgIN.route("/enableSwEventReport", enableSwEventReport);
            bMsgRouted |= msgIN.route("/enableCommandErrorReport", enableCommandErrorReport);
            bMsgRouted |= msgIN.route("/enableUvloReport", enableUvloReport);
            bMsgRouted |= msgIN.route("/enableThermalStatusReport", enableThermalStatusReport);
            bMsgRouted |= msgIN.route("/enableOverCurrentReport", enableOverCurrentReport);
            bMsgRouted |= msgIN.route("/enableStallReport", enableStallReport);
            //bMsgRouted |= msgIN.route("/getDir", getDir);
            bMsgRouted |= msgIN.route("/getLimitSw", getLimitSw);
            bMsgRouted |= msgIN.route("/getLimitSwMode", getLimitSwMode);
            bMsgRouted |= msgIN.route("/setLimitSwMode", setLimitSwMode);
            bMsgRouted |= msgIN.route("/enableLimitSwReport", enableLimitSwReport);

            bMsgRouted |= msgIN.route("/setMicrostepMode", setMicrostepMode);
            bMsgRouted |= msgIN.route("/getMicrostepMode", getMicrostepMode);
            bMsgRouted |= msgIN.route("/getHomeSwMode", getHomeSwMode);
            bMsgRouted |= msgIN.route("/setHomeSwMode", setHomeSwMode);
            bMsgRouted |= msgIN.route("/setStallThreshold", setStallThreshold);
            bMsgRouted |= msgIN.route("/getStallThreshold", getStallThreshold);
            bMsgRouted |= msgIN.route("/setOverCurrentThreshold", setOverCurrentThreshold);
            bMsgRouted |= msgIN.route("/getOverCurrentThreshold", getOverCurrentThreshold);
            bMsgRouted |= msgIN.route("/setLowSpeedOptimizeThreshold", setLowSpeedOptimizeThreshold);
            bMsgRouted |= msgIN.route("/getLowSpeedOptimizeThreshold", getLowSpeedOptimizeThreshold);
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

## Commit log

2020-04-17 fixed some bugs and constants name of PowerSTEP01 Library
    [step400_proto_r4.brd, step400_proto_r4.sch]
2020-07-13 Update the current mode functions. FixedOCD_TH and STALL_TH bit length.
    [STEP400_proto_r4_firmware.ino]
2020-07-14 Added limit switch functions
2020-07-27 Added the schematics PDF, updated the Max example patch.
    [step400_proto_r4.sch]
2020-08-13 fixed some mistakes in maxpat
    [STEP400_proto_r4_firmware.ino]
2020-08-26 Fixed a bug on /getSpeedProfile
    [osc_listeners.ino]
2020-09-04 Fixed to multiple motors
2020-09-09 setup switch test code
2020-09-11 Updated Max sample patch
2020-09-24 Added the brakeboard design files
    [brakeBoard.brd, brakeBoard.sch]
2020-09-30 Added OSC error reports
    [osc_listeners.ino]
2020-10-02 Added a watchdog timer, fixed `/booted` message timing
    [STEP400_proto_r4_firmware.ino, diagnosis.ino, osc_listeners.ino]
2020-10-21 Added example config.txt
    [config.txt]
2020-10-23 Added some more example config.txt
    [config.txt]

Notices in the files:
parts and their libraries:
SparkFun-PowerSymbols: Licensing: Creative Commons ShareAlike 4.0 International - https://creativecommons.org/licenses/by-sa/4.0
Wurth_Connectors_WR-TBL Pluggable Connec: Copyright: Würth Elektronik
